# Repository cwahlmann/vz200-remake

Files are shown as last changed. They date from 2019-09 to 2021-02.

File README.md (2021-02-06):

# vz200-remake
Ein Nachbau des VZ200 Color Computers (Vtech / Dick Smith 1983)

**[==>> RESOURCEN & DOWNLOADS <<==](#resourcen-und-downloads)** 

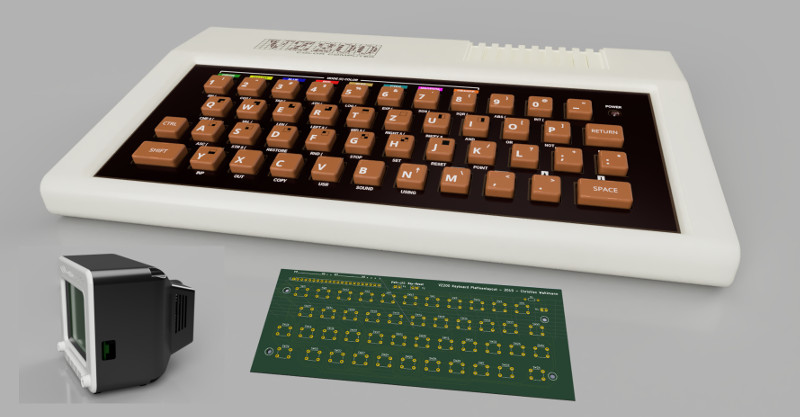
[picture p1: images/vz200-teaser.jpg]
Teaser VZ200 - 70%


**[=> Design und Druck der Bauteile](01_druck.md)**

**[=> Platinendesign und -produktion](02_platinendesign.md)**

**[=> Zusammenbau des VZ200](03_zusammenbau_vz200.md)**

**[=> Zusammenbau des Monitors mit TFT-Display, Raspberry-Pi und Lautsprecher](04_zusammenbau_monitor.md)**

**[=> Installation des Raspberry Pi](05_installation.md)**

**[=> Der VZ200 Emulator](06_emulator.md)**

**[=> VZ200 Companion App](apps/README.md)**

**[=> Nützliche Links](08_links.md)**

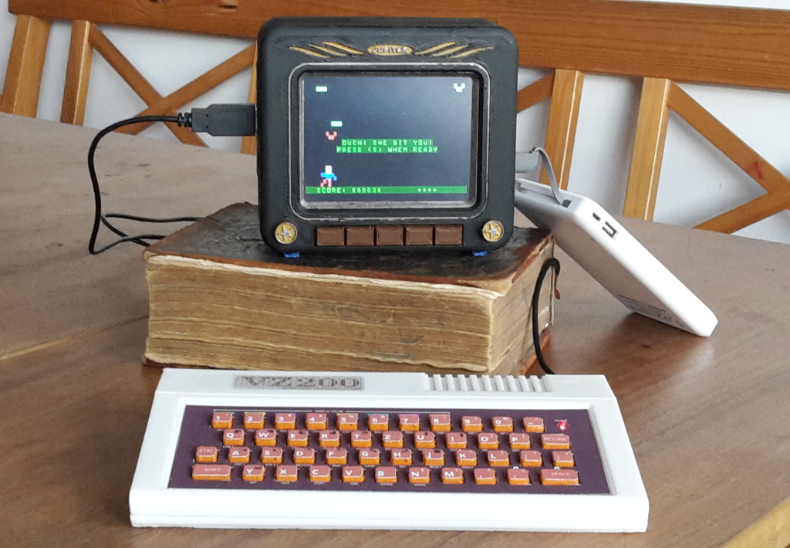
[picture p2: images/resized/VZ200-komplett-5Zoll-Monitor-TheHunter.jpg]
Prototyp VZ200 - 70%


## Resourcen und Downloads

Hardware
* [STL files auf Thingiverse](https://www.thingiverse.com/thing:4415555)
* [3d-Modell VZ200 (.f3d, Fusion 360)](resources/3d-model/vz200.f3d)
* [3d-Modell VZ200 (.fbx, Blender-kompatibel)](resources/3d-model/vz200.fbx)
* [3d-Modell Monitor (.f3d, Fusion 360)](resources/3d-model/Monitor_5-Zoll.f3d) 
* [3d-Modell Monitor (.fbx, Blender-kompatibel)](resources/3d-model/Monitor_5-Zoll.fbx) 
* [Gerber-Dateien für die Tastaturplatine](resources/gerber/vz200-keyboard-layout.zip)
* [Grafiken für die Tastatur](resources/aufkleber/Aufkleber-2x70perc.png)
* [Grafiken für das Logo](resources/aufkleber/logo_7x70perc_A4.png)

Software
* [JemuVZ200 Emulator V2.4 - NEW australian gfx mod, fix issue with vz loader](resources/releases/JemuVZ200-2.4.zip)
* VZ200 Companion App (TODO)

Dokumentation und Beispiele
* [Z80 Befehlssatz](resources/doc/z80.pdf)
* [VZ200 Basic Befehlssatz](resources/doc/VZ200-Basic.pdf)
* ["Hello World" (Assembler) Tutorial](resources/doc/tutorial/hello-world-asm-tutorial.pdf)
* ["Side Scrolling" (Assembler) Tutorial](resources/doc/tutorial/side-scroll-asm-tutorial.pdf)
* [Tutorial Präsentation (LibreOffice)](resources/doc/tutorial/VZ200-tutorial.odp)

Alle Sourcen sind zu finden unter
* [github.com/cwahlmann/vz200](https://github.com/cwahlmann/vz200)

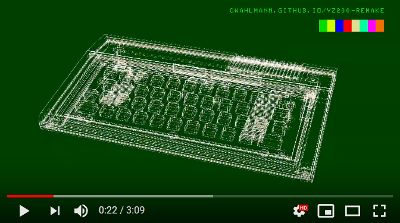
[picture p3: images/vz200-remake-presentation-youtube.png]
VZ200 Presentation Makerfaire (https://www.youtube.com/watch?v=7TxQ1y71ufA)


Basic Programming
Charset
the hunter - bit by a bat

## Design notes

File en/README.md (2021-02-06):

# vz200-remake
A replica of the VZ200 Color Computer (Vtech / Dick Smith 1983)

**[==>> RESOURCES & DOWNLOADS <<==](#resources-and-downloads)** 

Teaser VZ200 - 70%

**[@ Designing and printing the Parts](01_print.md)**

**[@ Cirquit board design and production](02_cirquitboarddesign.md)**

**[@ Assembly of the VZ200](03_assembly_vz200.md)**

**[@ Assembly of the Monitor with TFT Display, Raspberry-Pi and Speaker](04_assembly_monitor.md)**

**[@ Installation of the Raspberry Pi](05_installation.md)**

**[@ The VZ200 Emulator](06_emulator.md)**

**[@ VZ200 Companion App](apps/README.md)**

**[@ Useful Links](08_links.md)**

Prototyp VZ200 - 70%

## Resources and downloads

Hardware
* [STL files on Thingiverse](https://www.thingiverse.com/thing:4415555)
* [3d-Model VZ200 (.f3d, Fusion 360)](../resources/3d-model/vz200.f3d)
* [3d-Model VZ200 (.fbx, Blender-compatible)](../resources/3d-model/vz200.fbx)
* [3d-Model Monitor (.f3d, Fusion 360)](../resources/3d-model/Monitor_5-Zoll.f3d) 
* [3d-Model Monitor (.fbx, Blender-compatible)](../resources/3d-model/Monitor_5-Zoll.fbx) 
* [Gerber-files for the keyboard circuit board](../resources/gerber/vz200-keyboard-layout.zip)
* [graphics for the keyboard](../resources/aufkleber/Aufkleber-2x70perc.png)
* [graphics for the logo](../resources/aufkleber/logo_7x70perc_A4.png)

Software
* [JemuVZ200 Emulator V2.4 - NEW australian gfx mod, fix issue with vz loader](../resources/releases/JemuVZ200-2.4.zip)
* VZ200 Companion App (TODO)

Documentation and examples
* [Z80 instruction set](../resources/doc/z80.pdf)
* [VZ200 Basic instruction set](../resources/doc/VZ200-Basic.pdf)
* ["Hello World" (assembler) tutorial](../resources/doc/tutorial/hello-world-asm-tutorial.pdf)
* ["Side scrolling" (assembler) tutorial](../resources/doc/tutorial/side-scroll-asm-tutorial.pdf)
* [Tutorial presentation (LibreOffice)](../resources/doc/tutorial/VZ200-tutorial.odp)

All Sources are hosted at
* [github.com/cwahlmann/vz200](https://github.com/cwahlmann/vz200)

VZ200 Presentation Makerfaire (https://www.youtube.com/watch?v=7TxQ1y71ufA)

Basic Programming
Charset
the hunter - bit by a bat

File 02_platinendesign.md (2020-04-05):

**[ZURÜCK](README.md)**
# <a name="platinendesign">Platinendesign und -produktion</a>

Eigenes Platinenlayout mit Dip-Schaltern (6mm; Höhe über Platine: 4,5mm; 4 Füße), die über eine Gummi-Tastaturmatte betätigt werden.
Tastaturcontroller: KEYWARRIOR24_8_MODUL_KW24_8_MOD

Das Layout kann, als Zip mit GBR-Dateien, über diverse Anbieter in kleiner Stückzahl (meist >= 3) produziert werden. 

Gute Erfahrungen haben wir mit [Aisler](https://aisler.net) gemacht. 

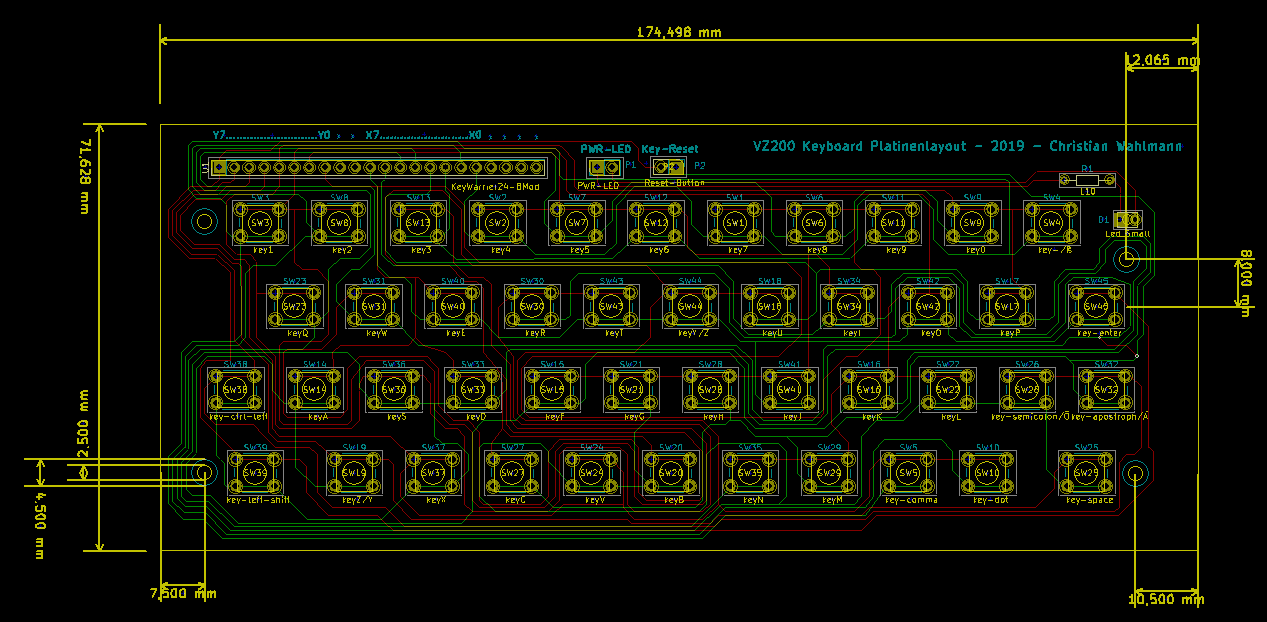
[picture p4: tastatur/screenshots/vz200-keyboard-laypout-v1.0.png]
Platinenlayout Keyboard

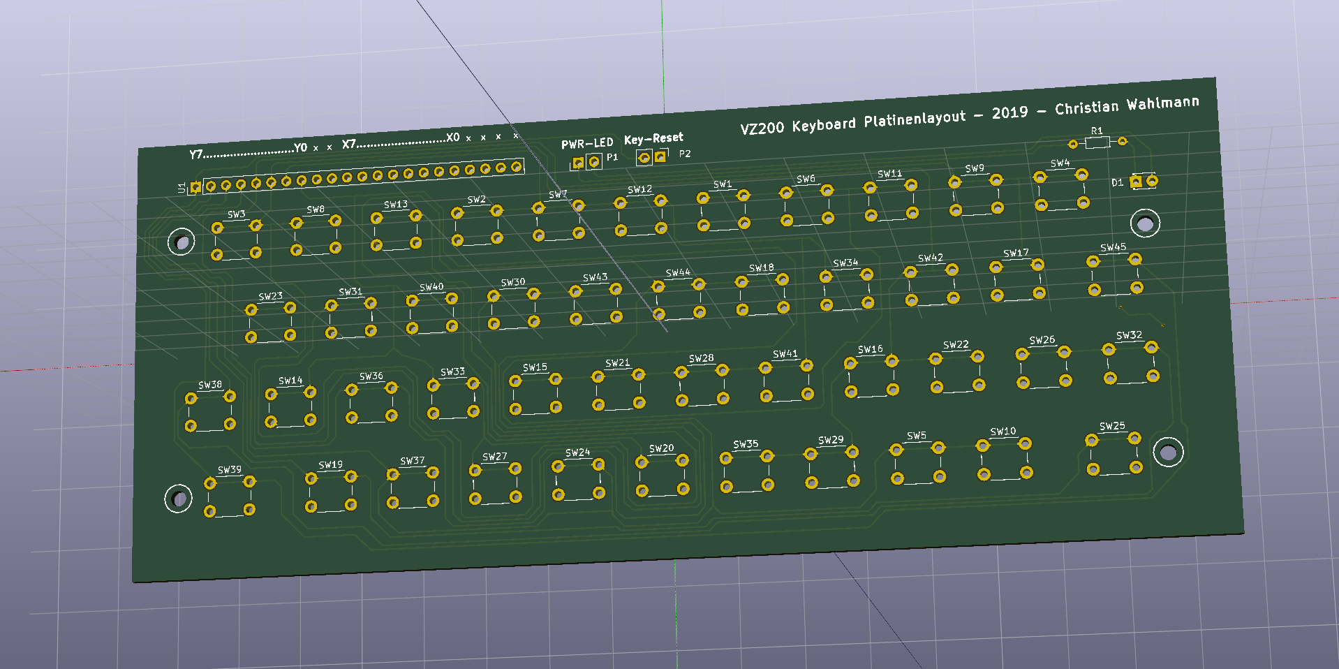
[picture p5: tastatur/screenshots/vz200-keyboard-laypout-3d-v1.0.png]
Platinenlayout Keyboard


**[ZURÜCK](README.md)**

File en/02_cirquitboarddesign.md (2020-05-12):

**[BACK](README.md)**
# <a name="circuitboarddesign">Cirquit board design and production</a>

Custom made cirquit board design with micro switches (6mm; height over board: 4,5mm, four stamps), which are operated through a TPU keyboard mat. Keyboard controller: KEYWARRIOR24_8_MODUL_KW24_8_MOD

This circuit board design can be produced by various workshops in small numbers, mostly require >= 3. Those workshops usually accept a zip file with GBR files.

Our boards were produced by [Aisler](https://aisler.net). 

Circuit design Keyboard
Circuit design Keyboard

**[BACK](README.md)**

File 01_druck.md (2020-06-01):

**[ZURÜCK](README.md)**
# <a name="druck">Design und Druck der Bauteile</a>
## 3d-Modell
Das Modell wurde mit Autodesk Fusion 360 erstellt. 

**Bitte beachten**: Das Modell des Computergehäuses und die darin verbaute Elektronik sind dafür 70% der Originalgröße ausgelegt. Die STL-Dateien geben das bereits wieder; in den Fusion-Dateien (.3mf) hat das Gehäuse noch die Originalgröße. Wer das Modell in Originalgröße nachbauen möchte, muss die Pfosten für den Tastaturcontroller anpassen und die Tastaturplatine entsprechend skalieren, bevor sie geätzt wird. Außerdem muss gegebenenfalls die Position der Resetschalter-Halterung angepasst werden.

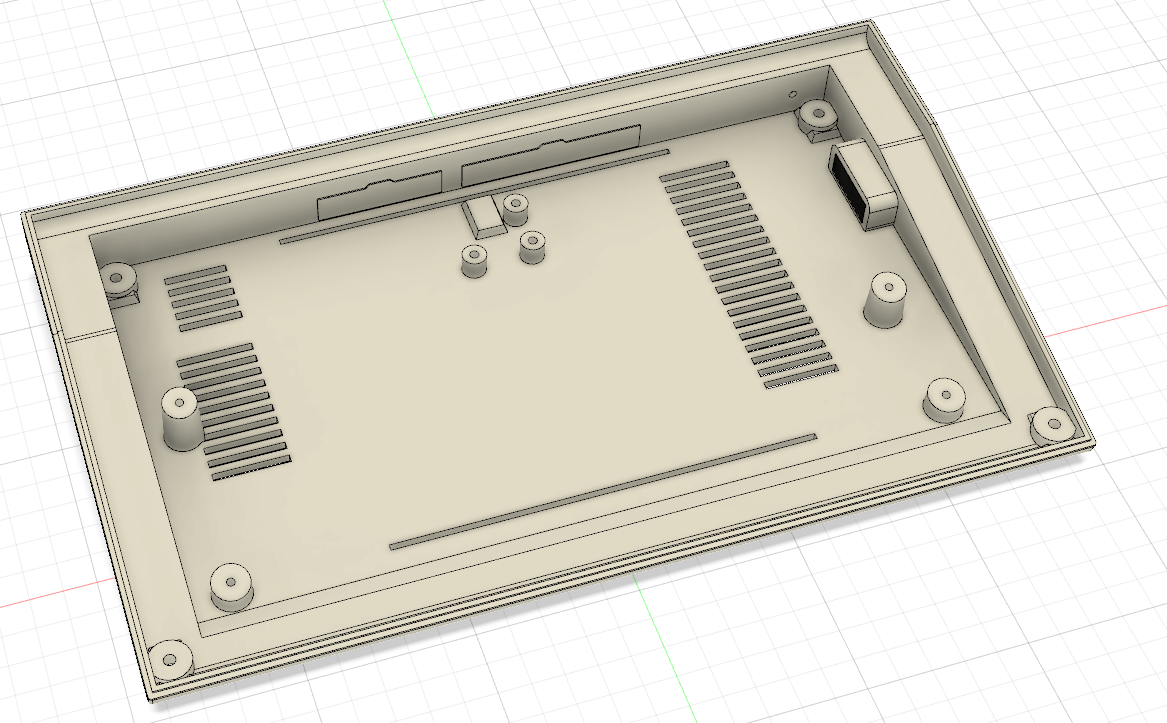
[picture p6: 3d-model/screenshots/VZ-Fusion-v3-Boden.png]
3d-Layout Boden

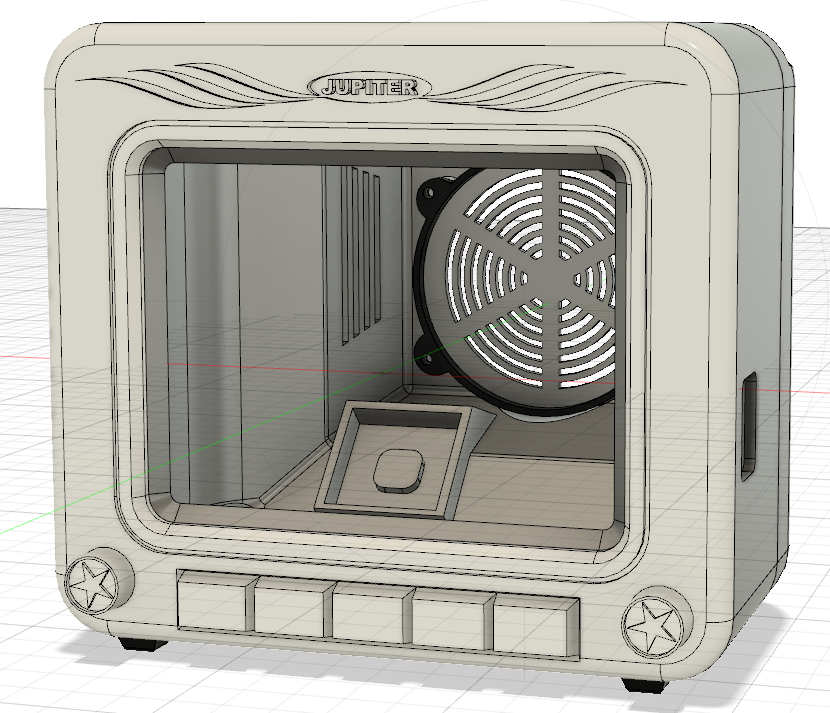
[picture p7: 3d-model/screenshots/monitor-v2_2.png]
3d-Layout Monitor


## Drucke

Druckdateien
* [STL files auf Thingiverse](https://www.thingiverse.com/thing:4415555)
* [3d-Modell VZ200](resources/3d-model/vz200.f3d)
* [3d-Modell Monitor](resources/3d-model/Monitor_5-Zoll.f3d) 

Die aus Fusion 360 exportierten STL-Dateien werden mit Ultimaker Cura 4.x druckfertig gemacht -> Das Projekt enthält gcode-Dateien für Creality Ender 3.

Gedruckt wird mit PLA (Gehäuse, Tastaturschablone, Resetschalter) und TPU-Filament (Tastaturmatte). 

Für den VZ 200 nehmen wir Weiß (Gehäuse), schokoladenbraun (Tastaturabdeckung) und eine beliebige TPU-Farbe für die Tastaturmatte (gummiartig).

**[ZURÜCK](README.md)**

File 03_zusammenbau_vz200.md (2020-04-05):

**[ZURÜCK](README.md)**
# <a name="zusammenbau">Zusammenbau des VZ200</a>

Das Chassis beherbergt eine funktionierende Tastatur mit Power-LED und Reset-Taster.

Bei einer Größe von 70 Prozent gegenüber dem Original-Rechner passt der Raspberry Pi nicht mit ins Gehäuse. Dieser wird deshalb in
den Monitor integriert. Der VZ200 wird als USB-Tastatur an den Raspberry angeschlossen. 

(Ein Raspberry-Zero würde in das Gehäuse passen, es muss jedoch getestet werden, ob dieser für den Emulator genügend Rechenpower liefert.)

## benötigte Bauteile

| Bauteil | Beschreibung |
| --- | --- |
| Gedruckte Teile | Boden, Abdeckung hinten, Tastatur (Rahmen, Schablone, Tastenmatte), Resetschalter + Klammer |
| Gedrucktes Logo | klare, selbstklebende, transparente A4 Polyesterfolie für Tintenstrahldrucker (z.B. von Photo Paper Direct PPD-39-20) |
| Gedruckte Tasten auf Vinylfolie | weiße, matte, selbstklebende A4 Vinylfolie für Tintenstrahldrucker (z.B. von Photo Paper Direct PPD-38-10) |
| Gedruckte Tastaturschablone auf Vinylfolie | weiße, matte, selbstklebende A4 Vinylfolie für Tintenstrahldrucker (z.B. von Photo Paper Direct PPD-38-10) |
| Modellfarbe für Tasten | EMAIL COLOR von Revell, Matt 35 (Hautfarben) und Matt 85 (Braun) |
| Tastaturplatine | mit Hilfe des Platinendesigns kann die Platine über diverse Anbieter gefertigt werden |
| Tastaturcontroller | ein USB-Keyboard-Controller mit vordefinierter Belegung: KEYWARRIOR24_8_MODUL_KW24_8_MOD |
| USB-Kabel | USB-Kabel mit Stecker und Litzen zum Einlöten |
| 45 Drucktaster | Bestückung der Tastaturplatine, 6x6 mm |
| 1 rote LED | die Power-LED, 3mm |
| 1 Widerstand | 150 Ohm (braun / grün / braun) |
| ein Stück Lochplatine | für den Drucktaster des Resetschalters, Lochabstand 2.54 mm |
| 1 Drucktaster | für den Resetschalter, 6x6 mm |
| 2 x Rot-Weiße Litze ca. 10 cm | für den Resetschalter und die Power-LED |
| 2 x 8-adriges Flachbandkabel ca. 10 cm | z.B. aus alten IDE-Flachbandkabeln, für die Verbindung Tastaturcontroler -> Tastaturplatine |
| ein Stück Isolierband | Abschirmung von Reset-Schalter und Tastaturplatine | 
| 7 kurze Schrauben M2 5mm | Befestigung von Tastaturplatine und -Controller |
| 2 kurze Schrauben M2 8mm | Befestigung der Reset-Schalter-Platine |
| 2 kurze M2 5mm und 2 lange M2 20mm Schrauben | Zusammenbau des Gehäuses |

## hintere Gehäuseabdeckung mit Logo versehen
Aufkleber Logo

Das gedruckt Logo muss wie abgebildet auf der hinteren Gehäuseabdeckung angebracht werden.

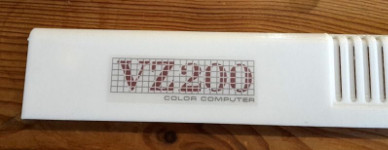
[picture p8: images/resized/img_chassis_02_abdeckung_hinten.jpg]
Abdeckung hinten


## Tastatur zusammenbauen
Benötigt werden die gedruckte Tastaturmatte, Modellfarbe und die gedruckten Tastenaufkleber.

Die Tasten der Matte müssen zunächst mit der Farbe (Matt 35, Hautfarben) mit einem Pinsel grundiert und dann
mit (Matt 85, Braun) gestrichen werden. Es sollten nur die Tasten selbst bemalt werden, damit die Matte gut zwischen Platine und Tastaturschablone passt und die Tasten leichtgängig bleiben. Ein Färben mit Sprühlack ist nicht zu empfehlen.

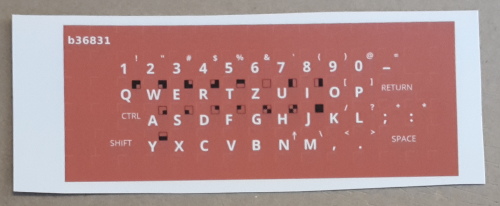
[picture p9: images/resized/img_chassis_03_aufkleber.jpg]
Tastaturmatte und Aufkleber Aufkleber

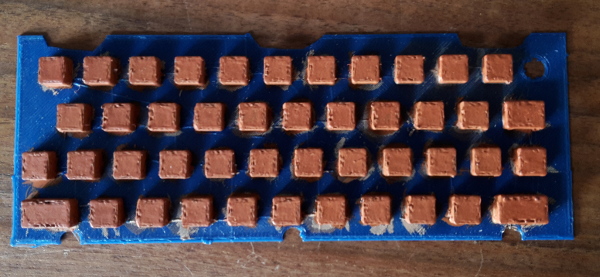
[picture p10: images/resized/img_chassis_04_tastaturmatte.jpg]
Tastaturmatte und Aufkleber Tastaturmatte


Die Aufkleber werden nun geschnitten.

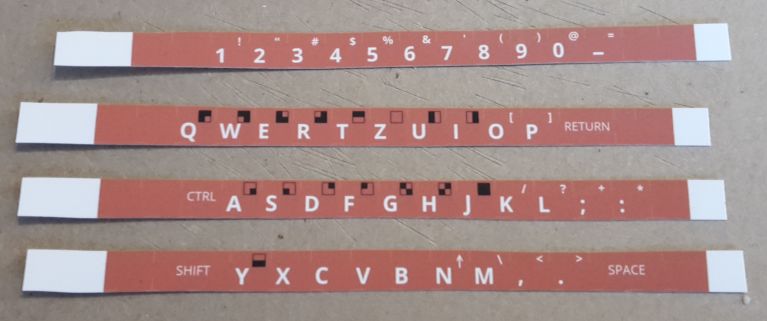
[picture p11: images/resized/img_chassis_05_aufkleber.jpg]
Tastaturaufkleber schneiden

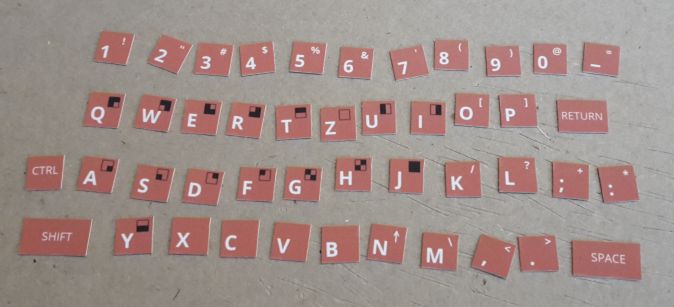
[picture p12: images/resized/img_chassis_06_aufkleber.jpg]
Tastaturaufkleber schneiden 2


Wichtig ist: damit die Tasten einen runden Eindruck machen, sollten die Ecken der Aufkleber diagonal angeschnitten werden.

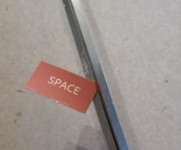
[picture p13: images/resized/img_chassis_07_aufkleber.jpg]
Tastaturaufkleber schneiden 3

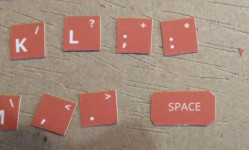
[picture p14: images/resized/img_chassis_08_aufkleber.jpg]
Tastaturaufkleber schneiden 4

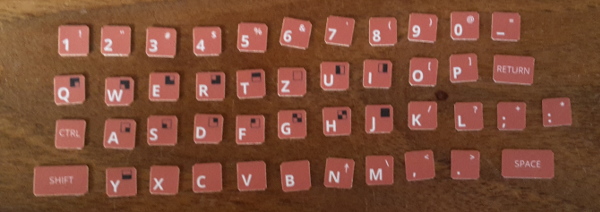
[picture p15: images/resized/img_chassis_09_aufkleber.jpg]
Tastaturaufkleber schneiden 5


Die geschnittenen Aufkleber werden auf die Tastaturmatte geklebt.

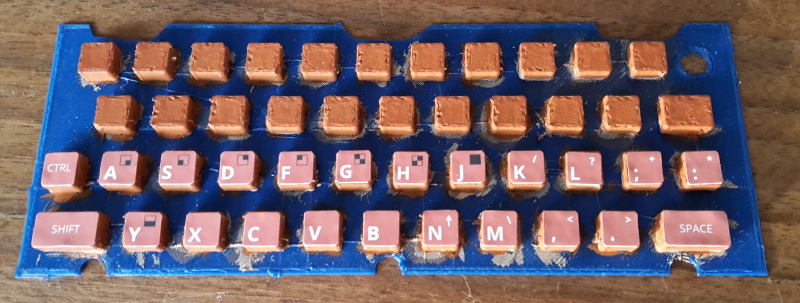
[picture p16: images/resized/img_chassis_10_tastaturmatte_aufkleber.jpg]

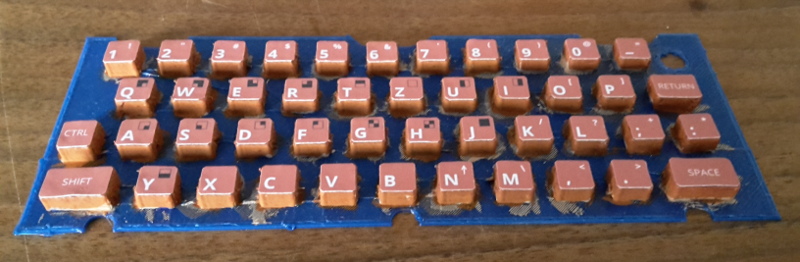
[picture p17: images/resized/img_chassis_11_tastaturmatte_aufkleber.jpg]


Nun wird die Tastaturschablone vorbereitet. Dazu wird die gedruckte Schablone und der gedruckte Aufkleber benötigt.

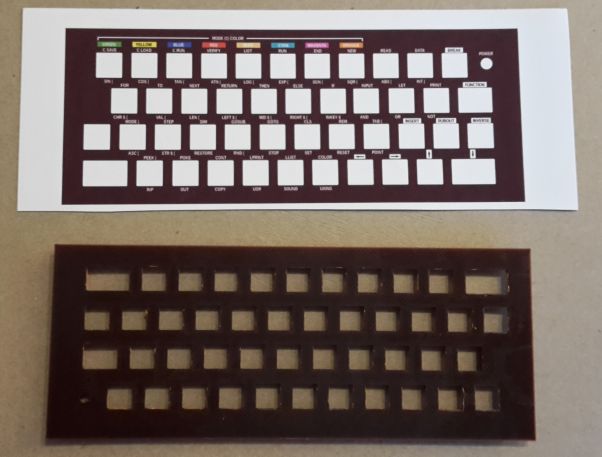
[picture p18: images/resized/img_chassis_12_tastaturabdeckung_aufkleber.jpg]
Tastaturschablone Aufkleber


Die Aussparungen für die Tasten und die Power-LED werden mit dem Cutter herausgetrennt.

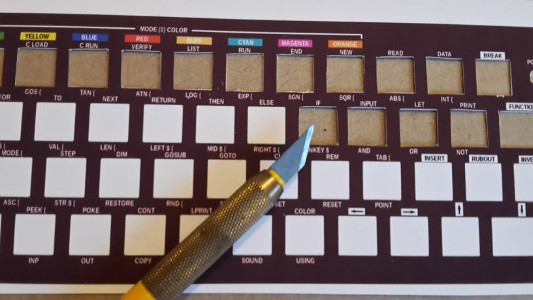
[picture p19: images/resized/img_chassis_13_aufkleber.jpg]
Tastaturschablone Aufkleber schneiden

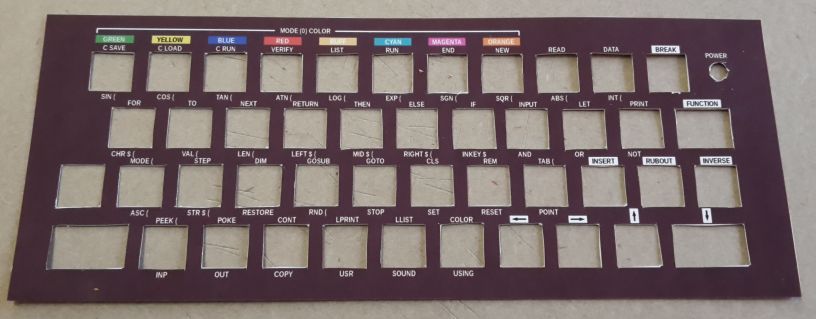
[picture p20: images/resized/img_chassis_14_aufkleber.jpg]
Tastaturschablone Aufkleber schneiden 2


Dann wird der Aufkleber auf die Schablone geklebt. Wichtig ist, dass die Aussparungen mittig auf die der Schablone geklebt werden. Dabei bleibt ein kleiner Rand, damit sich die Tasten nicht am Aufkleber verhaken.

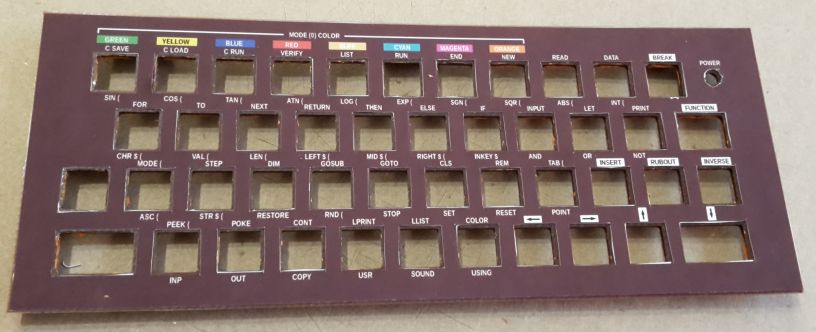
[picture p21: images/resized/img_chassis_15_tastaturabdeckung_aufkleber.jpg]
Tastaturschablone bekleben


Nun wird die Tastenmatte von hinten in die Schablone gesteckt, und die Schablone in den Tastaturrahmen eingehakt.

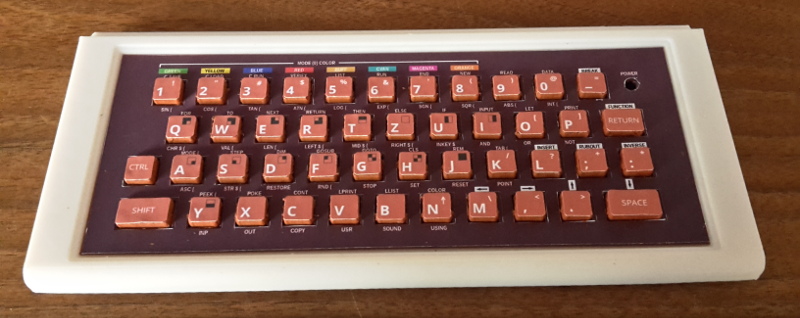
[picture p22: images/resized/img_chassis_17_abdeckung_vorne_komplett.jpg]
Tastaturschablone an Rahmen anbringen

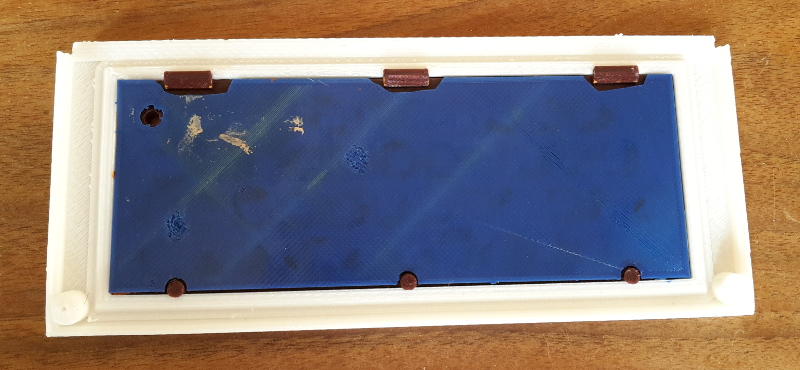
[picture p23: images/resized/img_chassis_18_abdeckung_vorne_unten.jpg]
Tastaturschablone im Rahmen unten


## Verlöten und Einbau der Elektronik

Im Bild eine Übersicht der benötigten Einzelteile:

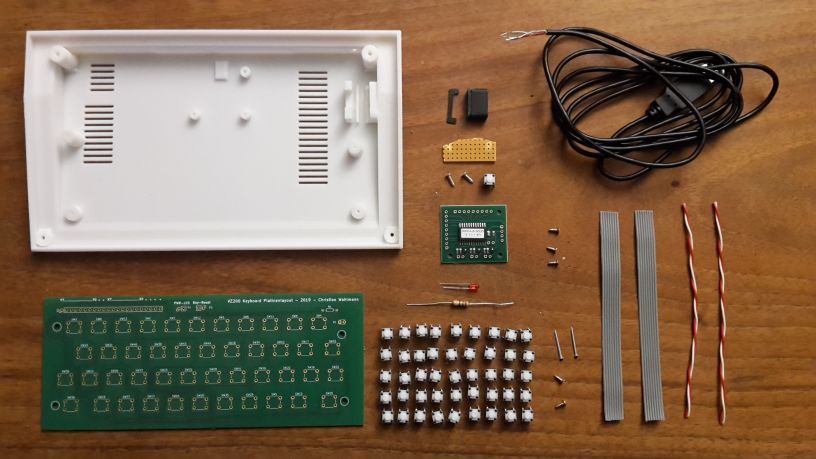
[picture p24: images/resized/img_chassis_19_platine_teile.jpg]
Bauteileübersicht Platine


Der Resettaster wird auf die zugeschnittene Lochplatine gesteckt.

Resettaster
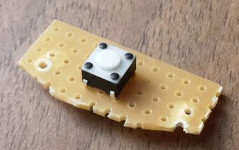
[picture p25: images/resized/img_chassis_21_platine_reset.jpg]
Resettaster 2


 Mit der Rot-weißen Litze wird der Taster mit der Tastaturplatine verbunden.

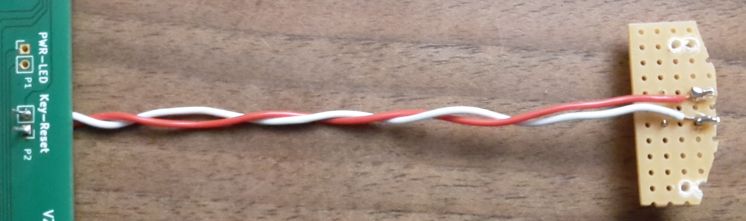
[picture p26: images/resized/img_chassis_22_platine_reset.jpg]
Resettaster 3


Dann werden noch zwei der kurzen Schrauben in die Platine geschraubt, zur späteren Befestigung am Boden des Gehäuses.

Resettaster 4

Das USB-Kabel wird wie abgebildet mit dem Tastaturcontroller verbunden.
**Achtung:** Das Kabel muss vor dem Löten durch das Loch des Gehäuseunterteils geführt und einfach verknotet werden!

| USB-Kabel Litzenfarbe | Controller Anschluss | 
| --- | --- |
| Rot | +5V |
| Weiß | D- |
| Grün | D+ |
| Schwarz | GND |

An +5V und GND wird zusätzlich die zweite Rot-Weiße Litze für die Power-LED angelötet:

| Power-LED Litzenfarbe | Controller Anschluss | 
| --- | --- |
| Rot | +5V |
| Weiß | GND |

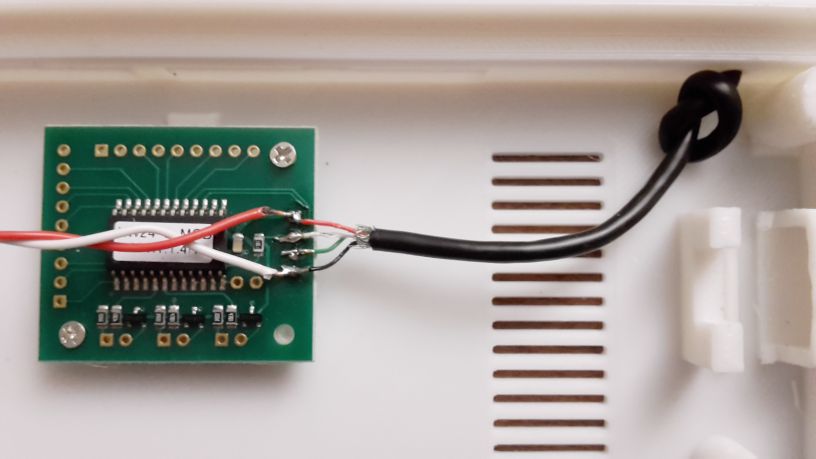
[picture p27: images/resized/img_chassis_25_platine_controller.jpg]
Tastaturcontroller 2


Nun werden die grauen Flachbandkabel an den Controller gelötet, an die Anschlüsse X0-X7 und Y0-Y7:

Tastaturcontroller 3
Tastaturcontroller 4

Jetzt wird die Tastaturplatine mit Tastern, der Power-LED und dem Vorwiderstand für die LED bestückt:

Platine Taster

Der Plus-Pol der LED (langes Bein) muss in den quadratischen Lötkontakt der Platine gelötet.

Platine Power-LED

Die Ausrichtung der Taster ergibt sich aus den Abständen der Lötkontakte auf der Platine.

Platine Taster 2

Nun wird die Rot-weiße Litze, welche an +5V / GND des Tastaturcontrollers angelötet ist, an die Tastaturplatine angelötet. Der weißumrandete Lötkontakt ist Minus (weiße Litze), der quadratische Kontakt ist Plus (rote Litze).
Danach werden die beiden Flachbandkabel an die Tastaturplatine gelötet. Hier ist sehr auf die Ausrichtung zu achten, die Lötkontakte der Tastaturplatine sind mit x0-x7 und y0-y7 beschriftet.

Platine Controller
Platine Controller 2

Nun wird der Reset-Taster ins Gehäuse eingebaut. Zunächst wird der gedruckte Reset-Schalter in das Gehäuse geschoben und mit der Klammer gesichert.

Platine Resettaster
Platine Resettaster 2

Dann wird die Platine mit dem Drucktaster aufgesetzt.

Platine Resettaster 3

Nun wird der Tastaturcontroller mit drei kurzen Schrauben in das Gehäuse geschraubt.

Platine Einbau

Auf den Reset-Taster wird etwas Isolierband geklebt, damit die Schraube unter der Tastaturplatine keinen Kurzschluss verursachen kann.

Platine Einbau 2

Die Platine wird mit vier kurzen Schrauben im Gehäuse befestigt.

Platine Einbau 3

Zuletzt werden der Tastaturrahmen und das hintere Gehäuseteil aufgesetzt und auf der Rückseite mit zwei langen und zwei kurzen Schrauben befestigt.

Zusammenbau Chassis
Zusammenbau Chassis 2
Zusammenbau Chassis 3

Damit ist der VZ200 fertig. Der Emulator "JEmu" kann übrigens sowohl auf einem Raspberry PI als auch auf einem PC betrieben werden. Der VZ200 fungiert dabei als USB-Tastatur.

Hinweis: Falls die Tastatur prellt (mehrere Zeichen pro Tastendruck erzeugt) oder verschiedene Buchstaben auf einmal erscheinen, dann gibt es vermutlich einen Kurzschluss zwischen zwei Microschaltern. Das kann schnell passieren, falls nicht alle der sehr feinen Litzen der Kabel sauber verlötet werden und ggf. zur Seite wegstehen. 

Um das zu beheben, empfehlen wir, die Platine von beiden Seiten um die betreffenden Tasten herum unter einer starken Lampe genau zu betrachten, eventuell unter der Zuhilfenahme einer Lupe. Selbst feinste Drähtchen reflektieren das Licht aus einem bestimmten Blickwinkel. Diese dann mit einem Cutter abheben und abschneiden, um den Kurzschluss zu beheben. 

Weitere Fehlerquelle: Kalte Lötstellen (das gilt für den kompletten Zusammenbau). Diese erkennt man daran, dass der Lötzinn nicht glänzt, sondern leicht matt und milchig erscheint. Diese Stellen bitte noch einmal nachlöten. 

**[ZURÜCK](README.md)**

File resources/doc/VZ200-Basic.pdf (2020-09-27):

VZ200 Basic Cheat Sheet

VZ200-Remake | github.com/cwahlmann/vz200-remake | Seite 1 von 2
REM <kommentar> | ein Kommentar | REM *** START ***
PRINT [<var1>;<...>;<varN>] | Ausgabe mit Zeilenumbruch | PRINT "HALLO";$N
PRINT <...>; | Ausgabe ohne Zeilenumbruch | PRINT "SAG MAL WAS";
PRINT @<n>,<...> | | PRINT @128,"ZEILE 5"
PRINT TAB(<n>);<...> | | PRINT TAB(3);“3“;TAB(20);“20“
| Formatierte Ausgabe
INPUT <var1>[,<...>,<varN>] | Eingabe von einer oder mehrerer Werte | INPUT A$, X, Y
NEW | Programmspeicher löschen | NEW
RUN [<n>] | Programm (ab Zeile n) starten | RUN 30
[LET] <var>=<wert> | Wert einer Variablen zuweisen
LIST [[n]-[m]] | Programm (Zeilen m bis n> auflisten | LIST -100
GOTO <n> | zu Zeile n springen | GOTO 20100
STOP | das Programm unterbrechen | STOP
CONT | das Programm fortführen | CONT
END | | END
CLEAR [<n>] | | CLEAR 5000
ABS(<n>) | liefert den positiven Wert einer Zahl | X = ABS(-12.33):REM 12.33
SGN(<n>) | | X = SGN(-12.33):REM -1
SQR(<n>) | liefert die Wurzel einer Zahl | E = SQR(25):REM 5
LOG(<n>) | | L = LOG(4.44):REM 1.49065
EXP(<n>) | liefert den Wert e^n | E = EXP(1):REM 2.71828
INT(<n>) | liefert den ganzahligen Anteil einer Zahl | I = INT(1.9334):REM 1

RND(<n>)

SIN(<n>) | liefert den Sinuswert einer Zahl
COS(<n>) | liefert den Cosinuswert einer Zahl | X = COS(W/180*3.1415):REM .866033
TAN(<n>) | liefert den Tangenswert einer Zahl | T = TAN(W/180*3.1415):REM .57733
ATN(<n>) | liefert den Arcus-Tangenswert einer Zahl | W = ATN(X/Y)/3.1415*180:REM 30
LEN(<string>) | liefert die Länge eines Strings | PRINT LEN("HALLO")
STR$(<n>) | wandelt eine Zahl in einen String um | PRINT STR$(1277):REM "1277"
VAL(<string>) | wandelt einen String in eine Zahl um | PRINT VAL("1277"):REM 1277
LEFT$(<string>, <n>) | liefert die ersten n Zeichen eines Strings | L$ = LEFT$("NINA",2): REM NI
RIGHT$(<string>, <n>) | liefert die n letzten Zeichen eines Strings | R$ = RIGHT$("NINA",2):REM NA
MID$(<string>, <m>, <n>) | liefert n Zeichen ab Position m eines Strings M$ = MID$("NINA",2,2):REM IN
ASC(<string>) | | PRINT ASC("A"):REM 65
CHR$(<n>) | wandelt einen Ascii-Wert in einen String um | PRINT CHR$(65):REM A
INKEY$ | | 10 IF INKEY$="" THEN 10
= < > <= >= <> | Vergleichsoperatoren
<bool> AND|OR|NOT <bool> | logische Und/Oder/Nicht-Verknüpfung | 20 IF A=2 AND B=3 THEN 40

setzt den Cursor an die angegebenen Position, n=x+32*y
setzt den Cursor weiter zu angegebenen Position innerhalb der Doppelzeile PRINT USING <format>;
<var1>,<…>,<varN>

PRINT USING "##.## / ##.##"; 1.23, 0.75

LET X=7
I%=-9
B$="PETER"

das Programm beenden (kein CONT mehr möglich)
dem Programm n Bytes Speicher reservieren (Default: 50 bytes)

liefert das Vorzeichen einer Zahl (-1, 0 oder 1)

liefert den natürlichen Logarithmus einer Zahl

liefert eine Zufallszahl zwischen 1 und n, oder eine rationale Zahl zwischen 0 und 1 für n=0

IF RND(2)=1 THEN PRINT "TOP" ELSE PRINT "FLOPP"

W=30:Y = SIN(W/180*3.1415):REM .499987

liefert den Ascii-Wert des ersten Zeichens eines Strings

liest ein Zeichen von der Tastatur, ohne zu warten
IF <bedingung>
THEN <befehl-true>
[ELSE <befehl-false>]

Bedingte Ausführung, je nach Ergebnis der Bedingung

IF A>=2 THEN PRINT "MEHRERE ERBSEN" ELSE PRINT "EINE ERBSE" IF X=0 THEN PRINT "NULL"

VZ200 Basic Cheat Sheet

VZ200-Remake | github.com/cwahlmann/vz200-remake | Seite 2 von 2
<n> AND|OR|NOT <m> | bitweise Und/Oder/Nicht-Verknüpfung | E = 3 OR 6:REM 7
| Zählt var von n bis m (mit Schrittweite s) | FOR I=10 TO 1 STEP -1:PRINT I:NEXT
NEXT [<var>] | | NEXT I
GOSUB <n> | Aufruf des Unterprogramms ab Zeile n | GOSUB 12345
RETURN | Unterprogramm beenden | RETURN
DIM <var>(<m>[,<n>[,<o>]]) | | DIM R$(2,5)
DATA <n1>[,<n2>,<...>] | Daten bereitstellen | DATA 1,2,"PILLE",3,4,"PALLE"
READ <var1>[,<var2>,<...>] | Daten in Variablen einlesen | READ A,B,M$
RESTORE | | RESTORE
PEEK(<adresse>) | liefert Wert einer Speicherstelle | B = PEEK(28672)
POKE <adresse>,<wert> | schreibt einen Wert in den Speicher
CLOAD ["<filename>") | lädt ein Programm von Cassette | CLOAD "SUPERSPIEL"
CRUN ["<filename>") | führt ein Programm von Cassette aus | CRUN "MEGASPOILER"
CSAVE ["<filename>") | Schreibt ein Programm auf Cassette | CSAVE "MEINS"
VERIFY ["<filename>") | | VERIFY "MEINS"
| Schreibt Werte auf Cassette | PRINT# "DATEN",1,2,"PILLE"
| liest Werte von Cassette | INPUT# "DATEN",A,B,M$
MODE(<n>) | | MODE(1)
SET(<x>,<y>) | setzt einen Grafikpunkt | SET(10,10)
RESET(<x>,<y>) | löscht einen Grafikpunkt | RESET(9,10)
POINT(<x>,<y>) | liefert die Farbe eines Grafikpunkts | 60 IF POINT(9,10)=0 THEN 100
SOUND <note>,<länge> | | SOUND 13,7:SOUND 0,4:SOUND 15,7
INP(<n>) | liest einen Wert von Port n | B=INP(123)
OUT <n>,<wert> | schreibt einen Wert in Port n | OUT 123,4

USR(<n>)

LLIST, LPRINT | wie LIST und PRINT, aber auf Druckerport
COPY | | COPY
Variablennamen | [A-Z]([A-Z0-9])?(%|$)? | A1$="MOIN": XY=9.333
String | eine Zeichenkette | S$="GUTEN TAG"
Float | | PI=3.1415927:m=1E9
Integer | eine Ganzzahl zwischen -32768 und 32767 | Z9%=16384

Textmodus

Grafikmodus | 128x64 Pixel, 4 Farben, 2 Paletten

FOR <var>=<n> TO <m>
[STEP <s>]
springe zum nächsten Schleifendurchlauf (der Indexvariable var)

Arrayvariablen deklarieren (1, 2 oder 3-dimensional)

Beim Lesen von Daten wieder von vorne beginnen

POKE 28672,1:REM EIN "A" LINKS OBEN AM SCREEN

Vergleicht auf Cassette gespeichertes Programm mit dem aktuellen Programm im Speicher
PRINT# "<filename>",
<wert1> [,<wert2><...>]
INPUT# "<filename>",
<var1> [,<var2><...>]
setzt den Grafikmodus
(0 = Text, 1 = Hires)

COLOR [<vordergrund>]
[,<palette>]

Setzt Vordergrundfarbe und / oder die Hintergrundfarbe

COLOR 4: REM VORDERGRUND BLAU COLOR ,0: REM HINTERGRUND GRÜN COLOR 1,1: REM GELB / CYAN Spielt einen Ton ab
note: 0 = Pause; 1 = A2; 31 = D#5 länge: 1-4 = n/8; 5= ¾; 7 = 1 ½; 6-9 = 1-3

Ruft eine benutzerdefinierte Maschinenroutine auf.
Startadresse: 788e (30862) Wert n:7921 (31009)

POKE 30862,LO:REM LOWBYTE DES PRG POKE 30863,HI:REM HIGHBYTE DES PRG E=USR(1234)

LLIST
LPRINT "HALLO DRUCKER"
macht einen Screenshot auf dem Druckerport

eine Fließkommezahl zwischen -1.701411E+/-38 und -1.701411E+/-38

32x16 Zeichen,
8 Farben, 2 Hintergrundfarben

grün, gelb, blau, rot, weiss, türkis, magenta, orange / grün, orange grün, gelb, blau, rot / weiss, türkis, magenta, orange

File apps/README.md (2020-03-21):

# VZ200 Companion App

This App supports the retro enthusiast while dealing with the VZ200 - Emulator. It allows for doing file transfers and operations on the emulated device as well as organizing files made available to the emulation. 



## Installation / prerequisites

### Install NPM

Download and install NodeJS from the official site.

https://nodejs.org/en/download/

### Install Ionic

> npm install -g ionic

### Install git

https://git-scm.com/downloads

## Build and run the App

Checkout the App from this repo into a directory of your choice:

> git clone https://github.com/cwahlmann/vz200/new/master/apps/VZ200-App

Install dependencies

> npm i

Run the App

> ionic serve

The App should be available at http://localhost:4200

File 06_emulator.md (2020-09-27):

**[ZURÜCK](README.md)**
# <a name="emulator">Der VZ200 Emulator</a>

Der genutzte Emulator ist eine angepasste Version des Java-Emulators 'jemu': http://jemu.winape.net/

## Port Konfiguration

application.properties (Default 8080):

```
server.port = 10101
```

Reset-Taste: [ESC]

## Erweiterung Netzwerk-Info

```basic
OUT 250,0:FOR I=1 to 4:PRINT INP(250);:NEXT
192 168 1 100
READY
```

PORT | IN / OUT | Beschreibung
-----|----------|-------------
250  | IN       | READ part of IP-Adress at [index] and increment [index]
250  | OUT      | SET [index] to [n] (0-3)

## Erweiterung Audio Device

```basic
OUT 251,0:REM SOUND OFF
READY
OUT 251,INP(251)+50:REM DO IT LOUDER
READY
```

PORT | IN / OUT | Beschreibung
-----|----------|-------------
251  | IN       | READ sound volume
251  | OUT      | SET sound volume to [n]

## Erweiterung laden / speichern von .vz:

```basic
OUT 252,1
READY
```

PORT | IN / OUT | Beschreibung
-----|----------|-------------
252  | OUT      | LOAD .vz program no. [n]
253  | OUT      | SAVE .vz program no. [n]

Alle Programme n <= 100 sind readonly.

(werden in [home]/vz200/vz abgelegt)

## Erweiterung Tape-Controle

```basic
PRINT INP(254)
10
READY
```

PORT | IN / OUT | Beschreibung
-----|----------|-------------
254  | OUT      | 0: STOP, 1: PLAY, 16: RECORD
255  | OUT      | REWIND to position [n]
254, 255  | IN  | get LSB / MSB of tape position

(werden in [home]/vz200/tape abgelegt)

## REST-Interface

Informationen zu den einzelnen Methoden können online abgerufen werden:

* Swagger-UI: [host:port]/api/swagger
* Open-API-Doc: [host:port]/v3/api-docs

## Australian Graphics Mod

PORT | IN / OUT | Beschreibung                        | Format
-----|----------|-------------------------------------|--------------------------------------------------
32   | OUT      | Grafikmodus und Gfx-RAM-Page setzen | ---MMMPP (MMM = Modus 0-7, PP = Gfx-RAM-Page 0-3)

| MODUS | Beschreibung
|---|---
| 0 | 64x64, 4 colors
| 1 | 128x64, monochrome
| 2 | 128x64, 4 colors (default)
| 3 | 128x96, monochrome
| 4 | 128x96, 4 colors
| 5 | 128x192, monochrome
| 6 | 128x192, 4 colors
| 7 | 256x192, monochrome

Der Mod kann über die Konfigurationsdatei ~/.jemu deaktiviert / aktiviert (default) werden.

**[ZURÜCK](README.md)**

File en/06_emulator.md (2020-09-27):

**[BACK](README.md)**
# <a name="emulator">The VZ200 Emulator</a>

This Emulator is an adapted Variant of the Java-Emulator 'jemu': http://jemu.winape.net/

## Port Configuration

application.properties (Default 8080):

```
server.port = 10101
```

Reset Key: [ESC]

## Expansion to get network info

```basic
OUT 250,0:FOR I=1 to 4:PRINT INP(250);:NEXT
192 168 1 100
READY
```

PORT | IN / OUT | Description
-----|----------|-------------
250  | IN       | READ part of IP-Adress at [index] and increment [index]
250  | OUT      | SET [index] to [n] (0-3)

## Expansion for audio

```basic
OUT 251,0:REM SOUND OFF
READY
OUT 251,INP(251)+50:REM DO IT LOUDER
READY
```

PORT | IN / OUT | Description
-----|----------|-------------
251  | IN       | READ sound volume
251  | OUT      | SET sound volume to [n]

## Expansion to load and save .vz files:

```basic
OUT 252,1
READY
```

PORT | IN / OUT | Description
-----|----------|-------------
252  | OUT      | LOAD .vz program no. [n]
253  | OUT      | SAVE .vz program no. [n]

All programs with n <= 100 are readonly and have be stored in [home]/vz200/vz.

## Expansion Tape Control

```basic
PRINT INP(254)
10
READY
```

PORT | IN / OUT | Description
-----|----------|-------------
254  | OUT      | 0: STOP, 1: PLAY, 16: RECORD
255  | OUT      | REWIND to position [n]
254, 255  | IN  | get LSB / MSB of tape position

(Stored in [home]/vz200/tape)

## REST Interface

Information about the provided methods is available online at:

* Swagger-UI: [host:port]/api/swagger
* Open-API-Doc: [host:port]/v3/api-docs

## Australian Graphics Mod

PORT | IN / OUT | Description                       | FORMAT    
-----|----------|-----------------------------------|--------------------------------------------------
32   | OUT      | set graphic-mode und Gfx-RAM-Page | ---MMMPP (MMM = mode 0-7, PP = gfx-RAM-page 0-3)

| MODE  | Description
|---|---
| 0 | 64x64, 4 colors
| 1 | 128x64, monochrome
| 2 | 128x64, 4 colors (default)
| 3 | 128x96, monochrome
| 4 | 128x96, 4 colors
| 5 | 128x192, monochrome
| 6 | 128x192, 4 colors
| 7 | 256x192, monochrome

Der Mod kann über die Konfigurationsdatei ~/.jemu deaktiviert / aktiviert (default) werden.

**[BACK](README.md)**

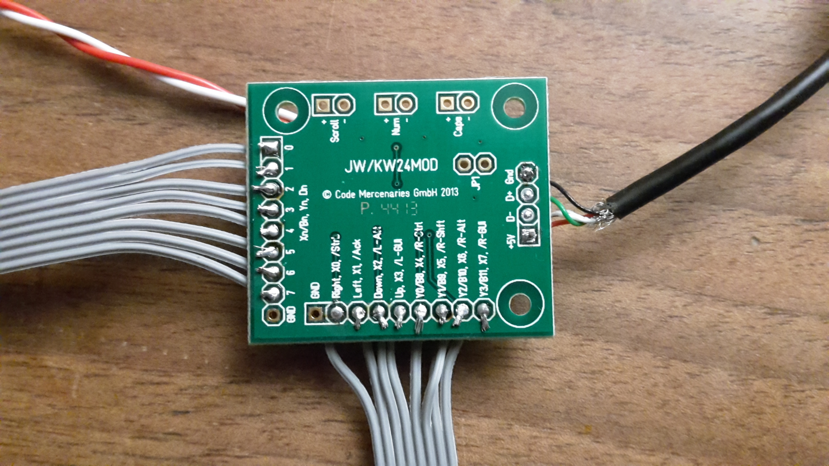
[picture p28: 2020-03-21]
images/img_chassis_27_platine_controller.jpg

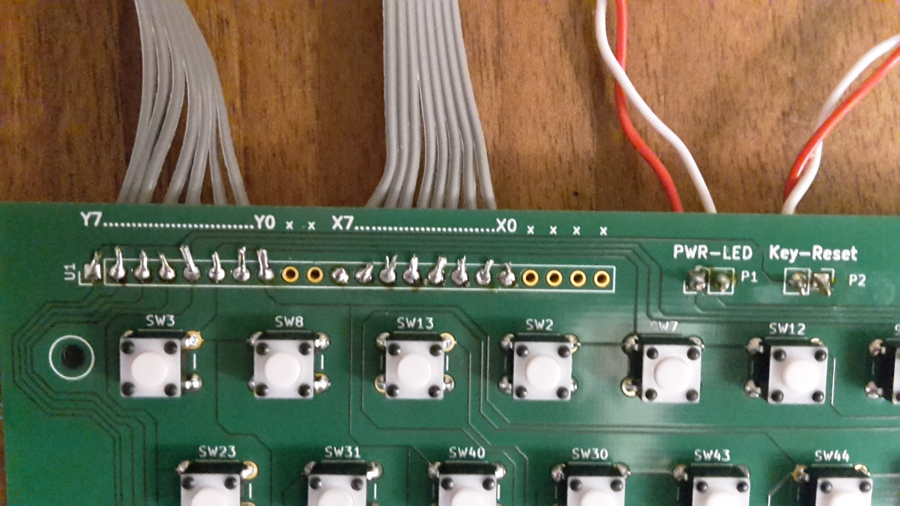
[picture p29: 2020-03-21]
images/img_chassis_32_platine_controller.jpg

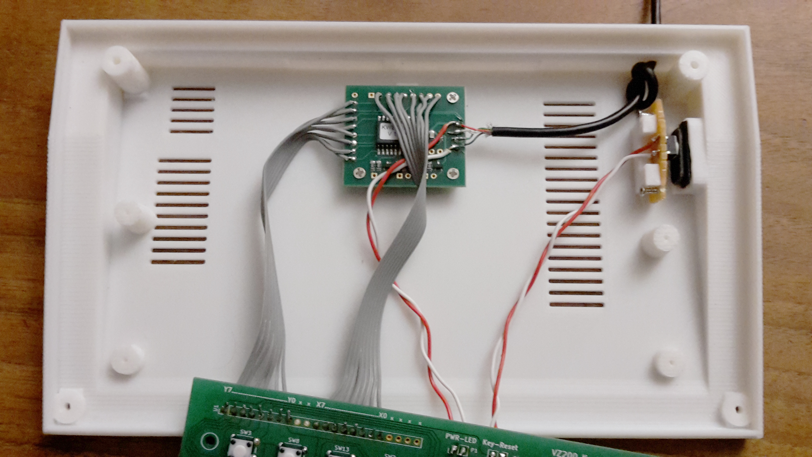
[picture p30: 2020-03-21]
images/img_chassis_36_platine_einbau.jpg

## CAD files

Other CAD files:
resources/3d-model/Monitor_5-Zoll.f3d

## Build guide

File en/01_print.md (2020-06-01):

**[BACK](README.md)**
# <a name="print">Designing and printing the Parts</a>
## 3d Model
The model has been designed with Autodesk Fusion 360.

**Word of advice**: The model of the computer case and the electronics within are sized at 70% of the original size. The STL files do reflect this already, though in the Fusion files (.3mf) the case still has it's original size. If you want to build the replica in 100% you need to adjust the ports for the keyboard controller and circuit board before having it being acit-treat. Also most likely the positon of the reset button holder needs to be adapted.

3d-Layout bottom 3d Layout bottom
3d-Layout Monitor 3d Layout Monitor

## Resources and downloads

Hardware
* [STL files on Thingiverse](https://www.thingiverse.com/thing:4415555)
* [Gerber-files for keyboards circuit board](../resources/gerber/vz200-keyboard-layout.zip)
* [Graphics for the keyboard](resources/aufkleber/Aufkleber-2x70perc.png)
* [Graphics for the logo](resources/aufkleber/logo_7x70perc_A4.png)

Software
* [JemuVZ200 Emulator V2.0](resources/releases/JemuVZ200-2.0.zip)
* VZ200 Companion App (TODO)

Documentation and Examples
* [Z80 instruction set](resources/doc/z80.pdf)
* [VZ200 Basic instruction set](resources/doc/VZ200-Basic.pdf)
* ["Hello World" (assembler) tutorial](resources/doc/tutorial/hello-world-asm-tutorial.pdf)
* ["Side Scrolling" (assembler) tutorial](resources/doc/tutorial/side-scroll-asm-tutorial.pdf)
* [Tutorial presentation (LibreOffice)](resources/doc/tutorial/VZ200-tutorial.odp)

Sources are available at:
* https://github.com/cwahlmann/vz200-remake

## Printing

The STL files exported from Fusion 360 have to be prepared and sliced for printing, we used Cura 4.x. This project already contains GCODE files for Creality Ender 3. 

We recommend printing with PLA for the VZ200 Case, the keyboard mask and the reset button. For the keyboard mat a flexible material is required, like NinjaFlex or TPU.

With the VZ200 we use white for the case, chocolade brown for the keyboard mask and any color for the keyboard mat, it will be painted later anyways.

**[BACK](README.md)**

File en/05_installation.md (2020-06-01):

**[BACK](README.md)**
# <a name="installation">Prepare and install the Emulator on the Raspberry Pi</a>

## Build the project with Gradle

From the Emulator sub directory run
```
gradle createVZ200Zip
```

You'll get a zip file with all the files required located at `build\distributions\JemuVZ200.zip`.

## Install the desktop variant of Raspbian OS

Follow the instructions on https://www.raspbian.org/ by using the image for "Raspbian Buster Desktop Lite".

## Install the emulator

Copy and extract the Zip file to the home directory of the Raspberry.
The resulting directory structure should look like this:

```
pi@raspberrypi:~ $ unzip JemuVZ200.zip
Archive:  JemuVZ200.zip
   creating: vz200/
   creating: vz200/system/
   creating: vz200/system/vz/
   creating: vz200/system/vz/rom/
  inflating: vz200/system/vz/rom/VZ.CHR
  inflating: vz200/system/vz/rom/VZBAS12.ROM
  inflating: vz200/system/vz/rom/README.txt
   creating: vz200/tape/
  inflating: vz200/tape/README.txt
   creating: vz200/tape/default/
  inflating: vz200/tape/default/README.txt
   creating: vz200/vz/
  inflating: vz200/vz/README.txt
  inflating: vz200/vz200-all.jar
  inflating: desktop-wallpaper.png
  inflating: vz200.desktop
  inflating: vz200.sh
```

## Make the start script executable 

If you built the Emulator on a Windows machine perform two additional steps:

1. Install `dos2unix`:
```
sudo apt-get install dos2unix
```

2. Convert Linefeeds to Unix Style:
```
dos2unix vz200.desktop
dos2unix vz200.sh
```

Set Execute Flag:
```
chmod +x vz200.sh
```

## Launch Emulator automatically

Copy the file `vz200.desktop` to the autostart directory:
```
mkdir ~/.config/autostart
cp vz200.desktop ~/.config/autostart
```

## Install joe Text Editor

```
sudo apt-get install joe
```
(You may also use the already installed `nano` editor)

## Install JAVA and the ALSA Sound Driver

Install OpenJDK-8 Runtime and ALSA Driver by `apt-get`:
```
sudo apt-get install openjdk-8-jre
sudo apt-get install alsa-base alsa-utils
```

Adapt the Java Sound Configuration (comment PulseAudio, uncomment DirectAudioDevice):
```
sudo joe /etc/java-8-openjdk/sound.properties
#javax.sound.sampled.Clip=org.classpath.icedtea.pulseaudio.PulseAudioMixerProvider`
#javax.sound.sampled.Port=org.classpath.icedtea.pulseaudio.PulseAudioMixerProvider
#javax.sound.sampled.SourceDataLine=org.classpath.icedtea.pulseaudio.PulseAudioMixerProvider
#javax.sound.sampled.TargetDataLine=org.classpath.icedtea.pulseaudio.PulseAudioMixerProvider

javax.sound.sampled.Clip=com.sun.media.sound.DirectAudioDeviceProvider
javax.sound.sampled.Port=com.sun.media.sound.PortMixerProvider
javax.sound.sampled.SourceDataLine=com.sun.media.sound.DirectAudioDeviceProvider
javax.sound.sampled.TargetDataLine=com.sun.media.sound.DirectAudioDeviceProvider
```
Exit the Joe Editor by STRG-K and X.

Launch Raspi Configuration and change the following Settings:
- Switch audio to headphone 
```
sudo raspi-config
```

## Install the Splash-Screen:

Edit `/boot/config.txt`:
```
sudo joe /boot/config.txt
```
Add this line:
```
disable_splash=1
```

Edit `/usr/share/plymouth/themes/pix/pix.script`:
```
sudo joe /usr/share/plymouth/themes/pix/pix.script
```
Comment these lines:
```
message_sprite = Sprite();
message_sprite.SetPosition(screen_width * 0.1, screen_height * 0.9, 10000);
my_image = Image.Text(text, 1, 1, 1);
message_sprite.SetImage(my_image);
```

Edit `/boot/cmdline.txt`:
```
sudo joe /boot/cmdline.txt
```
- Replace `console=tty1` with `console=tty3`
- and add this parameter to the end of the line:
```
splash quiet plymouth.ignore-serial-consoles logo.nologo vt.global_cursor_default=0
```

Adapt Splash Screen:
```
sudo cp ~/vz200/desktop-wallpaper-1.png /usr/share/plymouth/themes/pix/splash.png
```
Source: https://scribles.net/customizing-boot-up-screen-on-raspberry-pi/

From within the Desktop Environment change the background image to `~/vz200/desktop-wallpaper-1.png`.

## Set Volume to Max:

```
amixer sset 'Master' 65536
```
Hide Taskbar: : Right Click on Taskbar -> Bar Settings -> Advanced: Minimize Task Bar when not used + Size when minimized: 0 Pixel

Adapt HDMI Settings in /boot/config.txt: `disable-overscan=1`, `hdmi_group=1`, `hdmi_mode=3`

After a reboot the Emulator should launch in Fullscreen Mode. 

**[BACK](README.md)**

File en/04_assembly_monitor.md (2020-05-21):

**[BACK](README.md)**
# <a name="monitor">Monitor Assembly with TFT Display, Raspberry-Pi and Speaker</a>

## Required Parts

| Part | Description |
| --- | --- |
| 3D Printed parts | Case Front and Back, Front Plate (optional), holding ring for speaker, 4 rubber feet (TPU) |
| Audio Amplifier | Mini Audio Amplifier PAM8403 DC 5V |
| 3.5" Stereo plug | best use a used one since it has to be ripped apart anyway |
| Speaker | 2" / 5 cm mini speaker 3 W 4 Ohm |
| Resistors for the voltage divider : 1x 1000 kOhm, 1x 47 Ohm| This divider reduces the voltage directly at the speaker to minimize volume and amplifier noise |
| Raspberry Pi | Modell >= 3b |
| TFT-Display | JOY-iT 5“ HDMI Touchscreen Display |
| 4 screws M2 6mm | To attach the speaker within the case |
| 4 screws M2 8mm | To assemble and fasten the case |
| 4 screws M2 6mm| To attach the display |
| Double side adhesive tape | To attach the Audio Amplifier |

Attention: Other than the VZ 200 model the Monitor parts do not need to be scaled down to 70%.

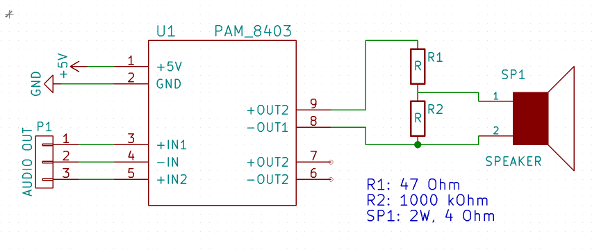
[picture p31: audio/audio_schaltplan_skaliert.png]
Audio schematics Audio Amplifier Schematics

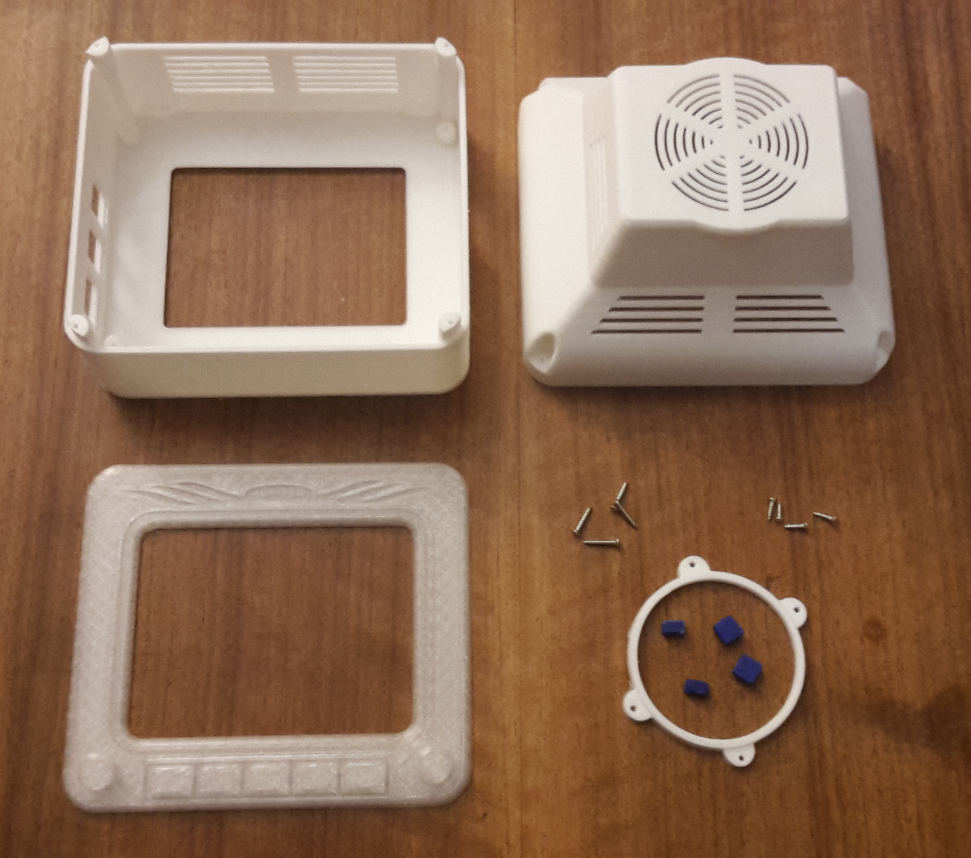
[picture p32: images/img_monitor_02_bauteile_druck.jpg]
Parts Printed

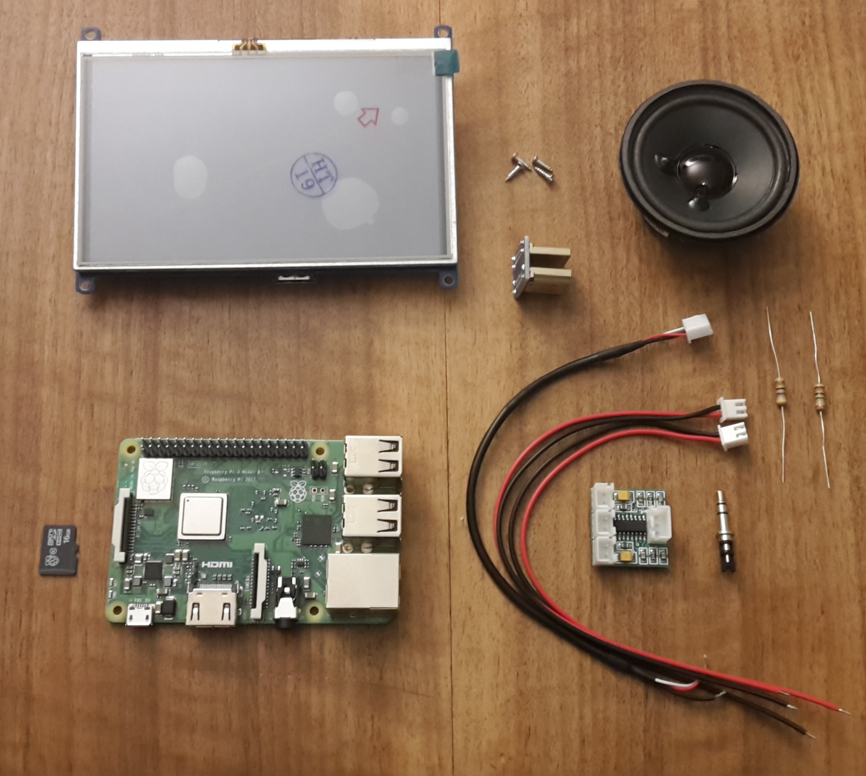
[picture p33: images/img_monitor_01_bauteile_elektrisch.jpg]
Electric parts


## Assemble the Monitor

Attach the TFT display to the GPIO Pins of the Raspberry and then connect both parts with the HDMI bridge.

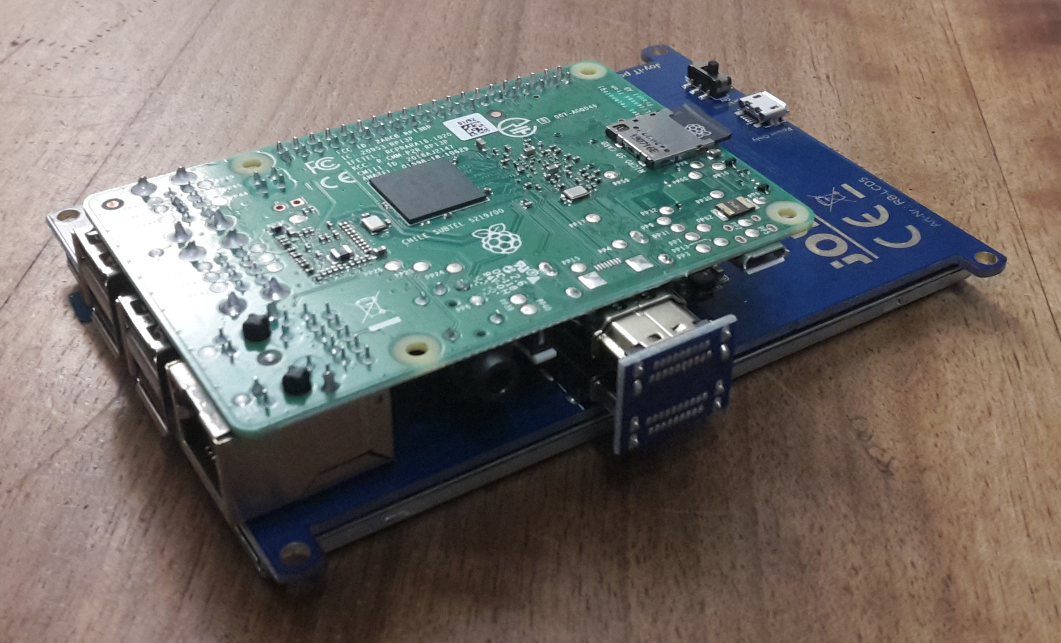
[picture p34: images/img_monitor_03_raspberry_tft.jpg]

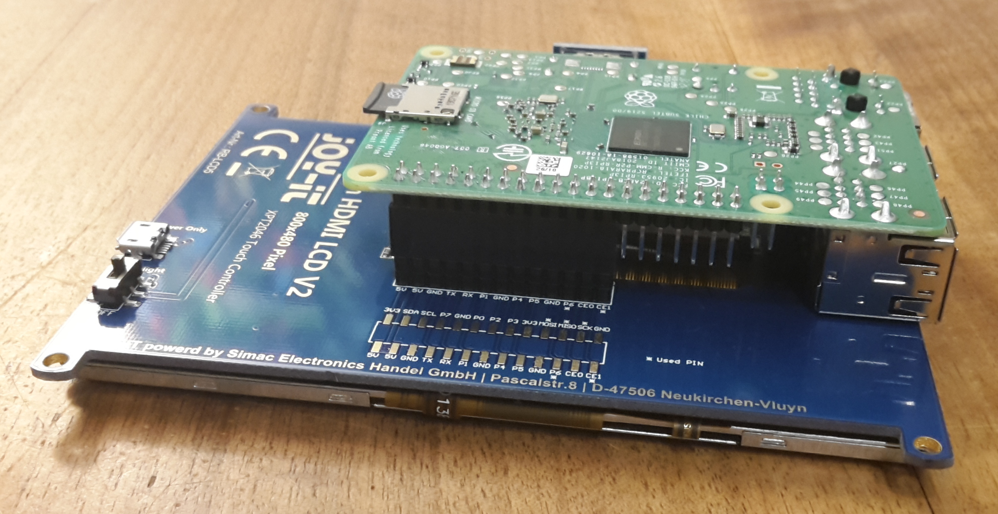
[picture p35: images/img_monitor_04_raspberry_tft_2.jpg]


The Audio Amplifier "PAM8403" amplifies the Raspberry signal quite a bit, yet also produces a lot of noise. By inserting a voltage divider and resistors both audio volume and noise will be dampened to an acceptable level.

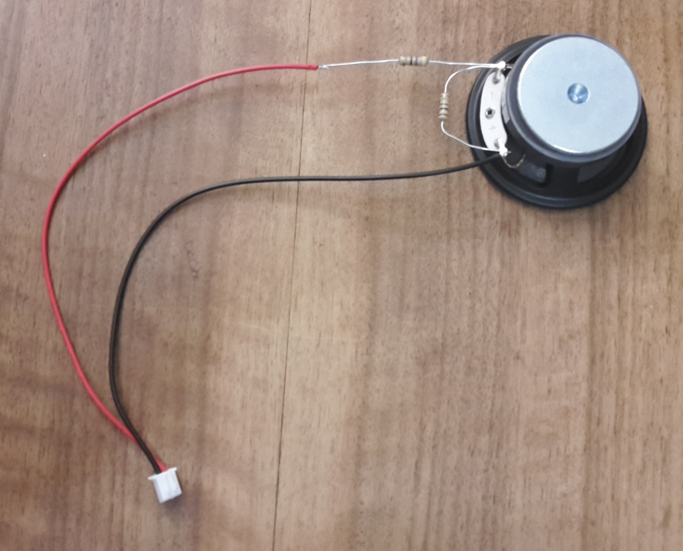
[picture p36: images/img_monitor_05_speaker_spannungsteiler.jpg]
Speaker voltage divider

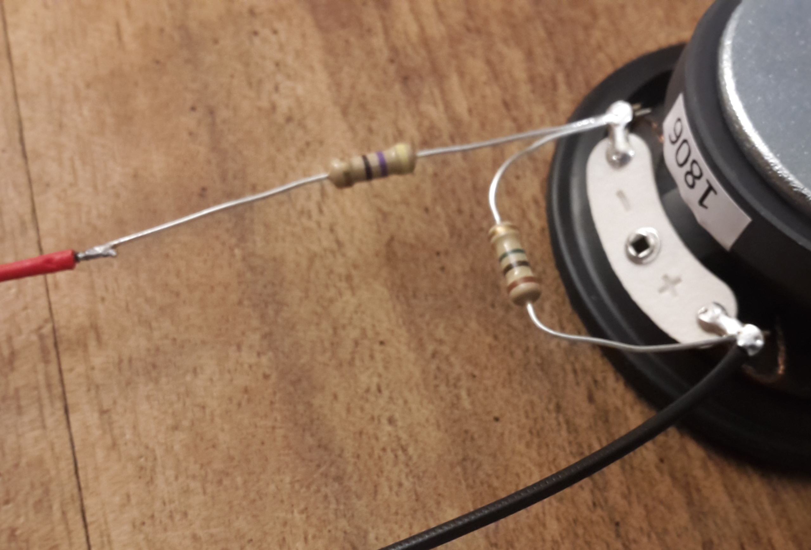
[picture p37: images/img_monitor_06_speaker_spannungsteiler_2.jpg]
Speaker voltage divider Detail


Solder the audio cable to the audio plug as shown here.

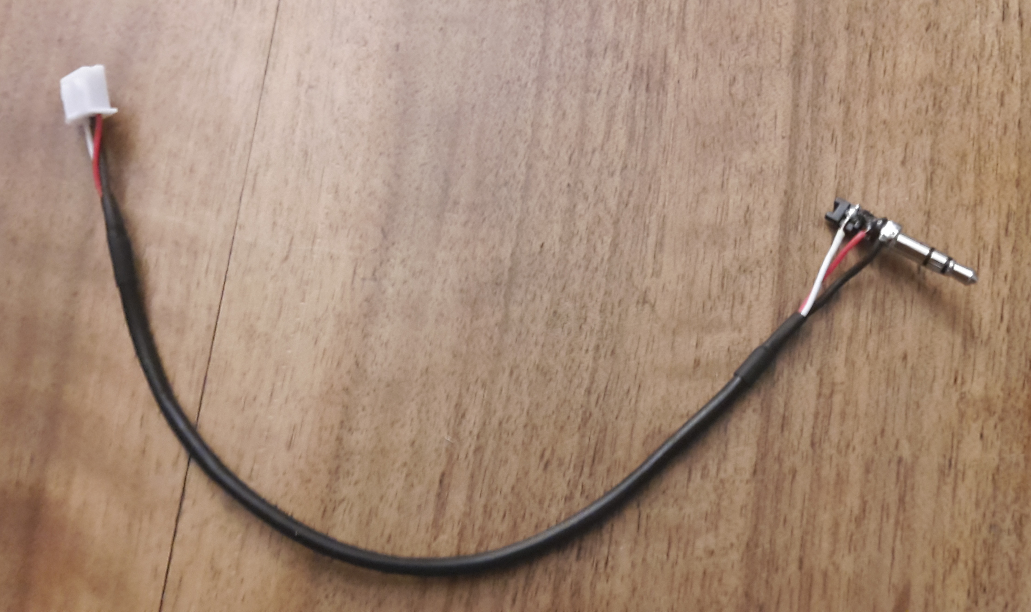
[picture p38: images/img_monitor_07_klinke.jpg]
Audio cable

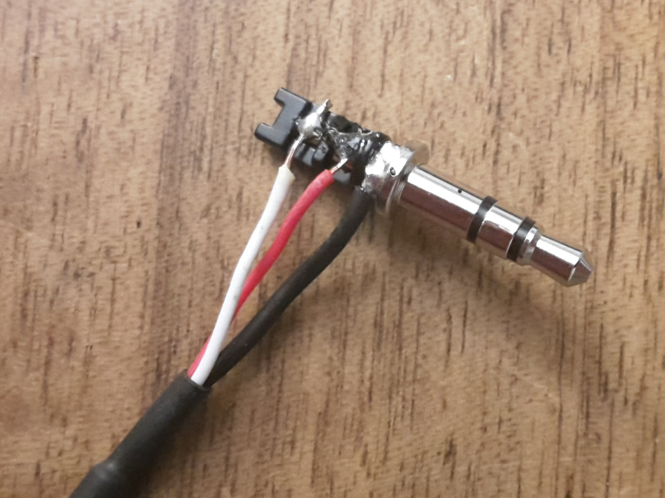
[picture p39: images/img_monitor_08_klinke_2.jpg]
Audio cable Detail


Power for the audio amplifier is taken from the GPIO pins of the TFT display (the display only utilizes a few Pins itself).

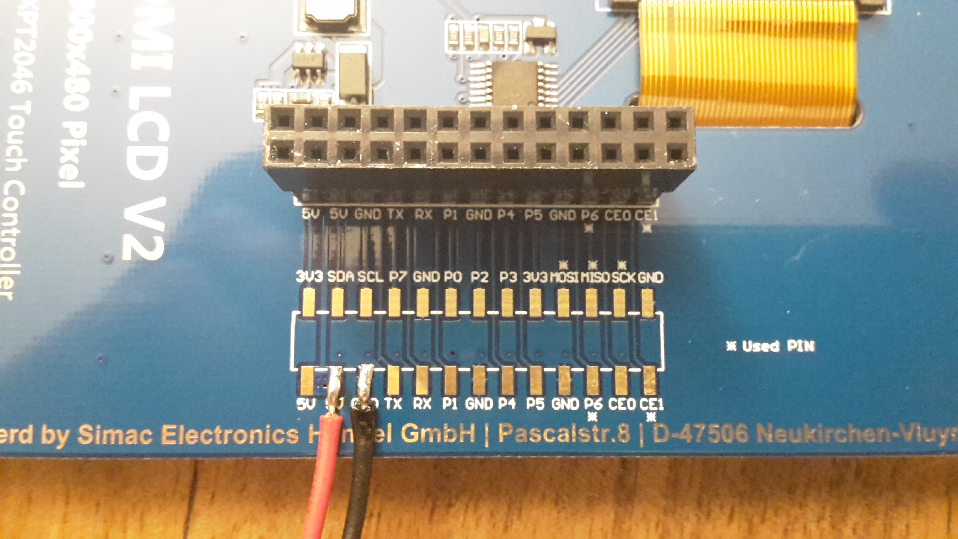
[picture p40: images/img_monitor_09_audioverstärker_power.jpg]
Solder Power Cable

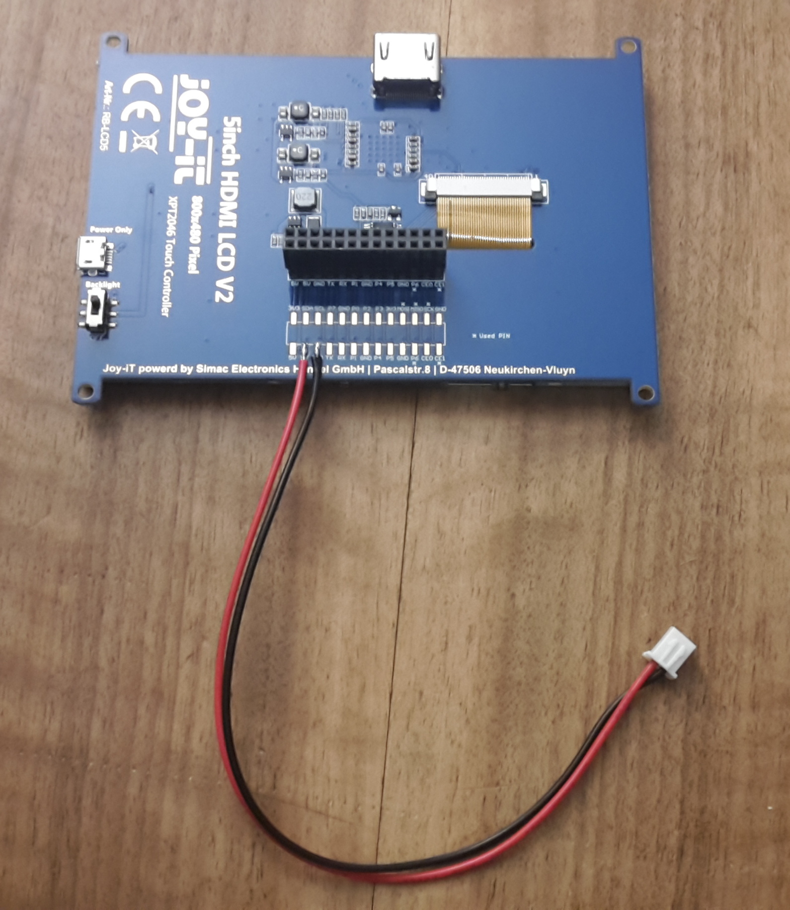
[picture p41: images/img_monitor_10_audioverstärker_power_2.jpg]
Power Cable


Here's how the completed cabeling looks like. Please pay attention to the labels on the amplifier board, those plugs must be plugged in with the correct orientation.

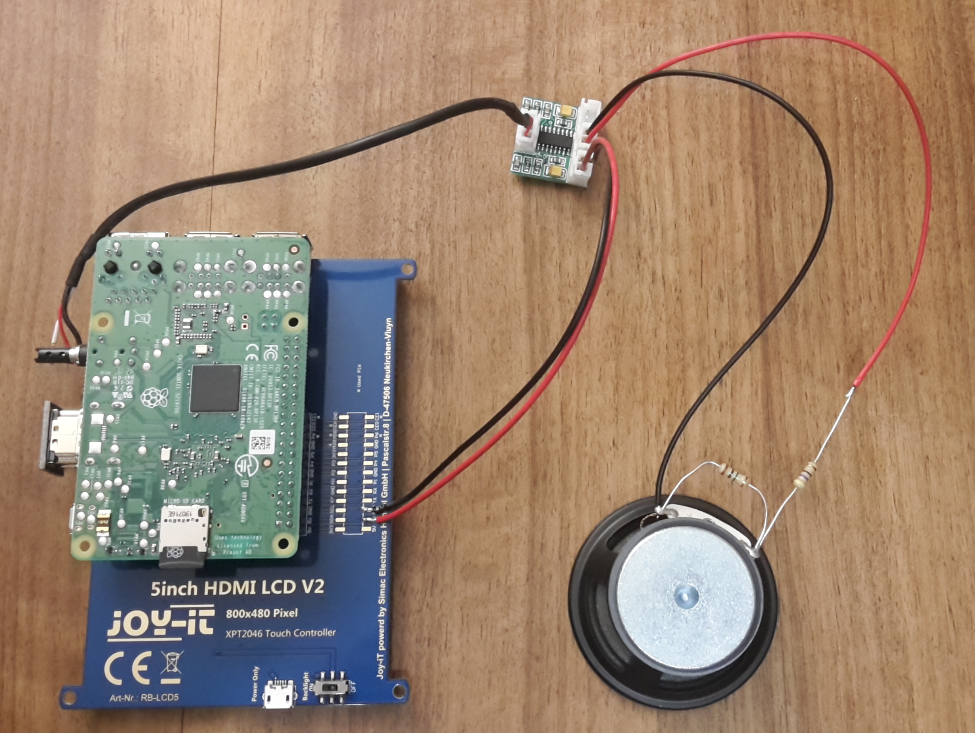
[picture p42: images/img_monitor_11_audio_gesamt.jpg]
Audio Cabeling


The VZ200 can be now run through a first test.

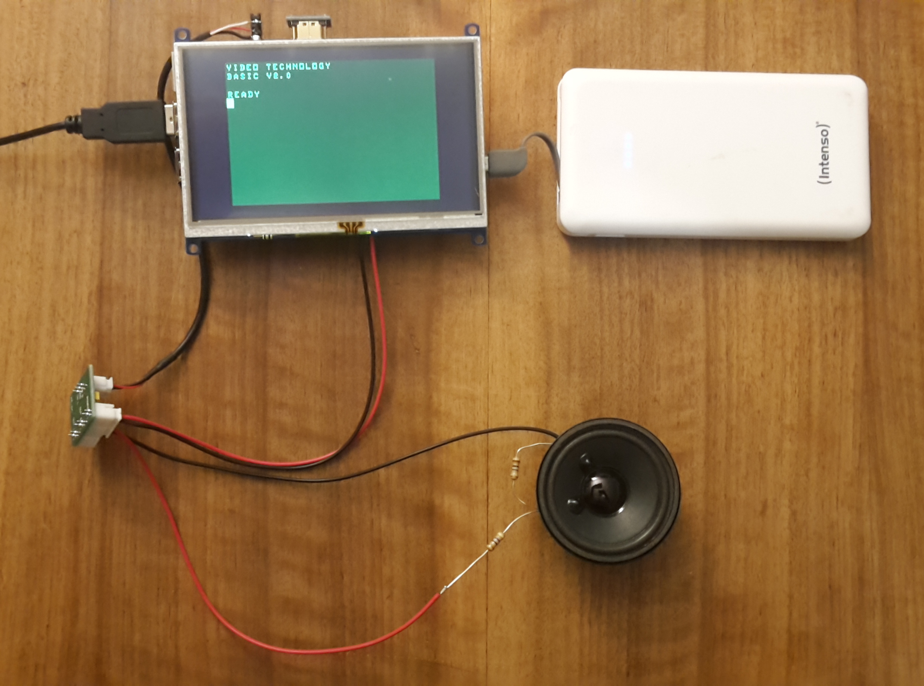
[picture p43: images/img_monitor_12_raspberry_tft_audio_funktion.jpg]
functional test


To avoid shortages, apply an isolating tape to the long resistor of the voltage divider. 

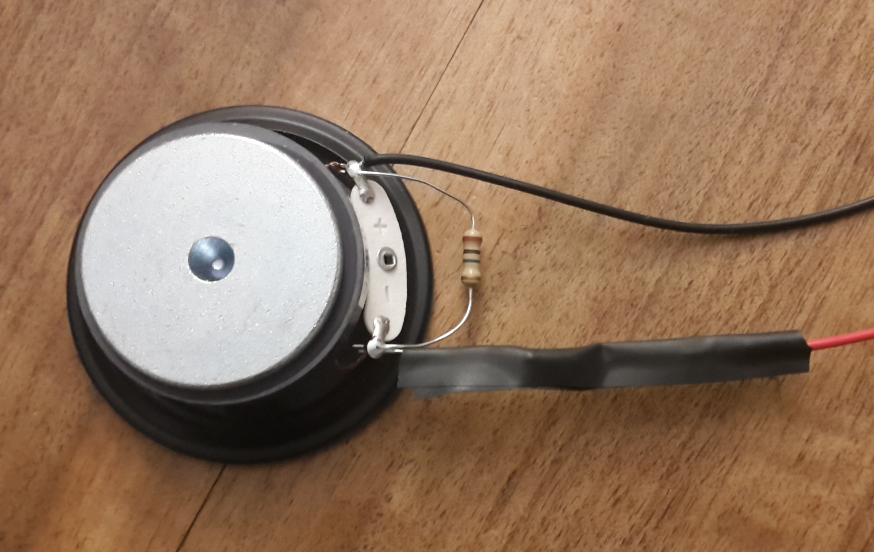
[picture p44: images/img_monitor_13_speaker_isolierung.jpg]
Speaker isolation


Attach the speaker with the 3D printed ring to the back case and fasten it with four screws. Use double side adhesive tape to attach the audio amplifier.

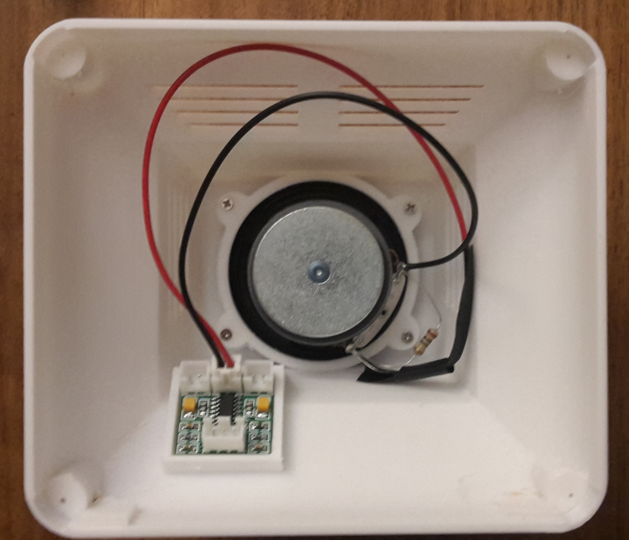
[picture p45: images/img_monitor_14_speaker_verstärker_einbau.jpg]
Monitor Speaker and Amplifier assembly


Then use another 4 screws to attach the TFT display with the plugged in Raspberry to the case front.

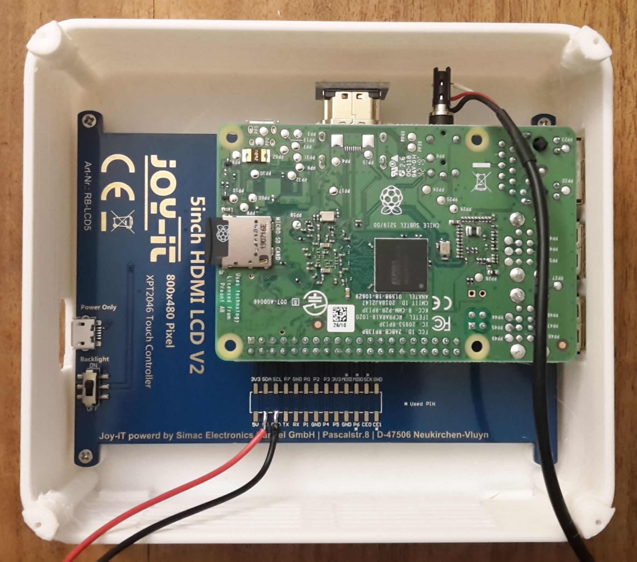
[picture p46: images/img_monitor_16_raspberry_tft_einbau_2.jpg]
Monitor TFT & Rasbpi assembly


To complete the monitor interior plug in all cables to the amplifier board and assemble the two monitor parts by fastening them with 4 screws.

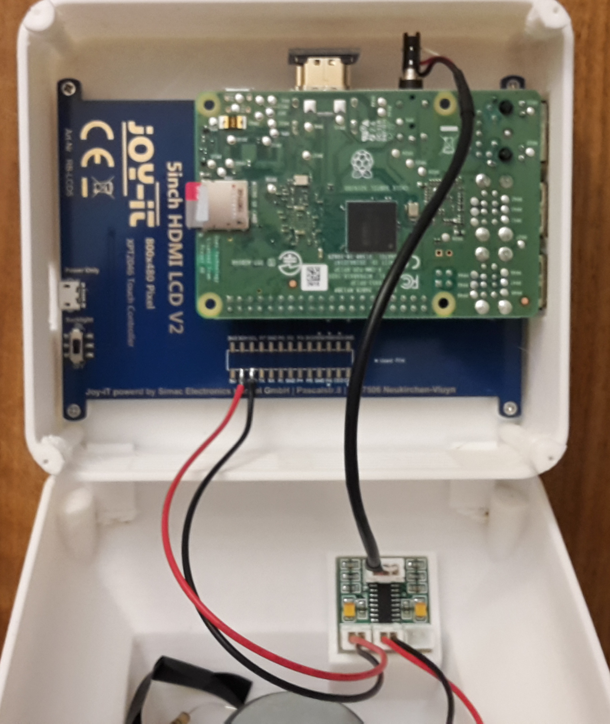
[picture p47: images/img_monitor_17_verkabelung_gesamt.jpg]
Cabeling


Glue the four monitor feet onto the bottom side of the monitor.

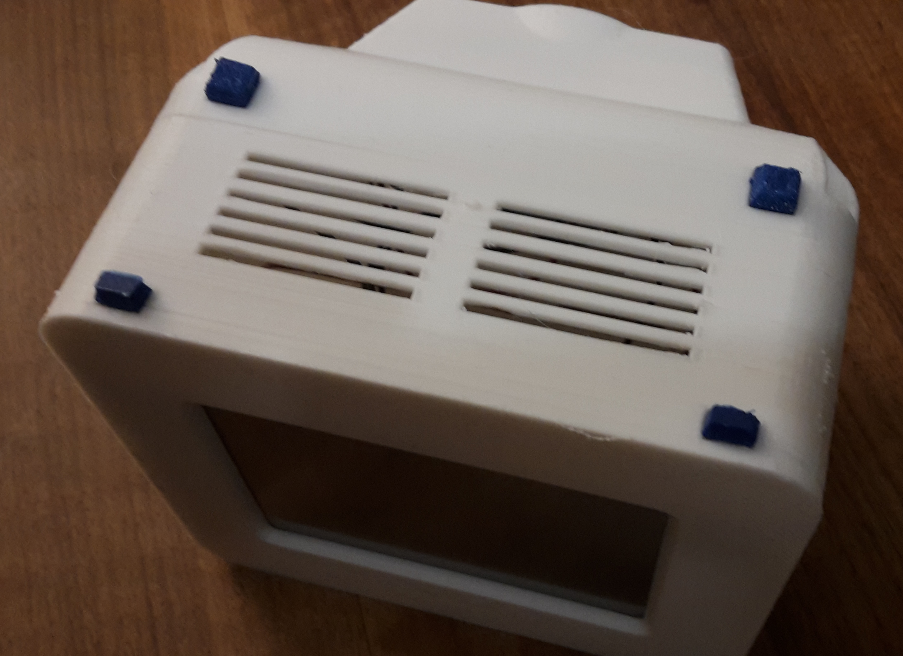
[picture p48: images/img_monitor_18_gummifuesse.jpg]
Glue rubber feet


Then either glue the seperately printed front panel to the front or design your own one. Hint: Paint the front panel beforehand to avoid compromising the TFT panel.

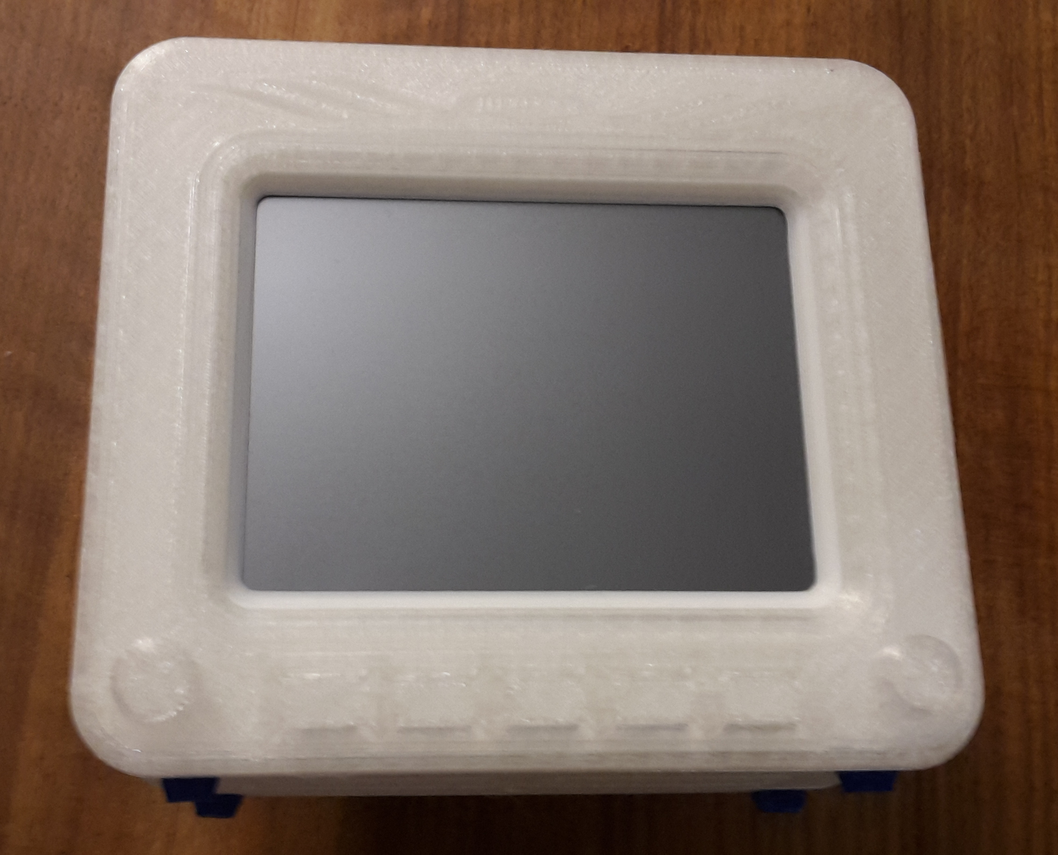
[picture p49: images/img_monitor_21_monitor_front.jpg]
Glue monitor front panel Glue monitor front pane


Now paint the rest of the monitor to your liking. If you already glued the front panel to the monitor, use masking tape to cover the TFT panel. Here is an example in a 1950er retro look;

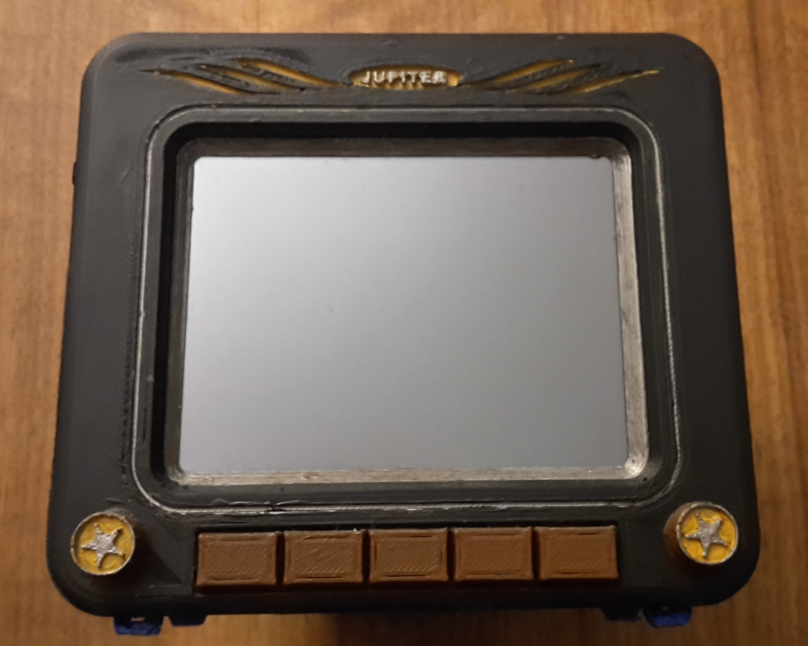
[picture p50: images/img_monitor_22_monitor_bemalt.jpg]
Painted Monitor


**[BACK](README.md)**

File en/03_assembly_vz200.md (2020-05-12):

**[BACK](README.md)**
# <a name="assemblyvz200">Assembly of the VZ200</a>

The case contains a fully functional keyboard with power LED and a reset button.

At a size of 70 % of the original VZ200 the Raspberry Pi will not fit into the case, thus it will be integrated into the monitor. The VZ200 will be connected to the Raspberry by a USB 2.0 cable.

## Required Parts

| Part | Description |
| --- | --- |
| 3D printed parts | Bottom case, Back cover, Keyboard (Frame, mask, keyboard mat), Reset Switch + Clamp |
| Printed Logo | clear, self adhesive and transparent A4 Polyester foil for ink jets |
| Printed Keys on vinyl sheet | white matt self adhesive A4 vinyl foil for ink jets |
| Printed Keyboard mask on vinyl sheet  | white matt self adhesive A4 vinyl foil for ink jets |
| Scale modeling color | e.g. EMAIL COLOR by Revell, matt 35 (skin tone) and matt 85 (brown) |
| Keyboard circuit board | available through various workshops by providing the accompanied GBR files |
| Keyboard controller | an USB keyboard controller with predefined mapping: KEYWARRIOR24_8_MODUL_KW24_8_MOD |
| USB cabel | USB cable with a 2.0 plug on one and bare wires on the other end |
| 45 micro switches | To be soldered to the keyboard cirquit board, 6x6 mm |
| 1 red LED | Power-LED, 3mm |
| 1 resistor | 150 Ohm (brown / green / brown) |
| Small piece of perforated circuit board | Used for the reset button, hole distance 2.54 mm |
| 1 micro switch | for the reset button, 6x6 mm |
| 2 x red / white wire ca. 10 cm | to connect the POWER LED and the reset button |
| 2 x 8 core flat cable ca. 10 cm | to connect keyboard controller to keyboard cirquit board |
| Isolation tape | to isolate reset button from keyboard cirquit board | 
| 7 small screws M2 5mm | to attach keyboard controller and cirquit board |
| 2 short screws M2 8mm | to attach reset button board |
| 2 short M2 5mm and 2 long M2 20mm screws | to assemble the VZ200 case |

## Attach the Logo to the back VZ200 casing
Sticker Logo

Apply the printed logo to the back case cover as shown in the picture.

Back case cover

## Assemble the keyboard
For this step you require the printed keyboard mat, the scale modeling color and the printed keyboard stickers. Do not use Airbrush or any other spraying color as this will soak the TPU and increase it's size substantially.

The keys of the mat need to be painted first with Revell Matt 35, Skin Color as a base color, then overpainted with Matt 35, brown. There is no need to paint the whole mat as it is also covered by the keyboard mask, plus this helps fitting the keys into the mask and allow them move freely.

Keyboard mat and stickers Stickers
Keyboard mat and stickers Keyboard Mat

The stickers have to be cut now.

Cutting the keyboard stickers
Cutting the keyboard stickers 2

Important notice: To achieve a rounded look cut the corners diagonally.

Cutting the keyboard stickers 3
Cutting the keyboard stickers 4
Cutting the keyboard stickers 5

The cut stickers are now applied on to the keyboard mat.

Applying the keyboard stickers
Applying the keyboard stickers

Now to prepare the keyboard mask. Have the 3d printed mask and the ink jet printed sticker ready.

Keyboard mask sticker

Now cut the holes for the keys and the Power LED.

Keyboard mask sticker cutting
Keyboard mask sticker cutting 2

Now the sticker will be applied to the mask. Carefully adjust the sticker to make sure the holes are centered around their counterparts on the mask.

There will be a small margin left so that the keys won't be hampered by the sticker.

Apply Keyboard mask sticker

Now the keyboard mat will be inserted into the mask's back and the mask inserted into the keyboard frame.

Insert Keyboard mask into the frame
Keyboard mask in frame from below

## Soldering and assemblying the electronics

The Image shows all the parts required:

Parts overview circuit board

The reset button goes onto the perforated mini board:

Reset button
Reset button 2

Connect the Reset button with the red / white wire to the keyboard circuit board.

Reset button 3

Then screw in the two short screws into the board to later attach it to the bottom case.

Reset button 4

Now connect the USB cable to the keyboard controller like shown here. 

**Attention:** The cabel needs to be put through the hole in the back of the bottom cover and knotted inside once to prevent drag on the cables.

| USB cable bare wire color | Controller port | 
| --- | --- |
| Red | +5V |
| White | D- |
| Green | D+ |
| Black | GND |

In addition solder the second red/white wire to +5V and GND for the Power LED.

| Power LED bare wire color | Controller port | 
| --- | --- |
| Redd | +5V |
| White | GND |

Keyboard Controller 2

Now solder the grey 8-core flat cable to the Controller, at the ports X0-X7 and Y0-Y7:

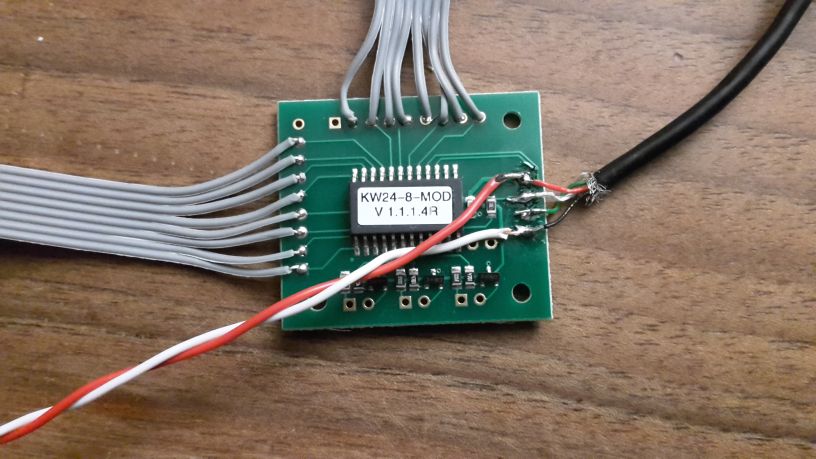
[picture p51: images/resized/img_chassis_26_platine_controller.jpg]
Keyboard Controller 3

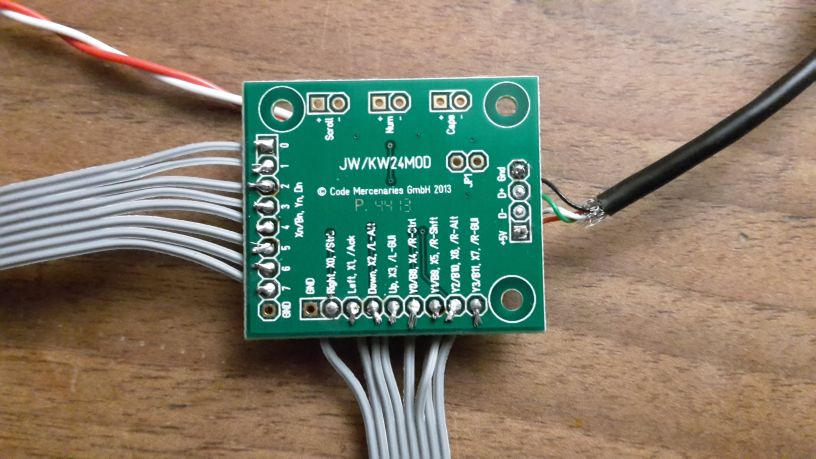
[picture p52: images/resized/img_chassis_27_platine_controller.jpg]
Keyboard Controller 4


Now add the micro switches, the Power LED and the resistor to the keyboard cirquit board:

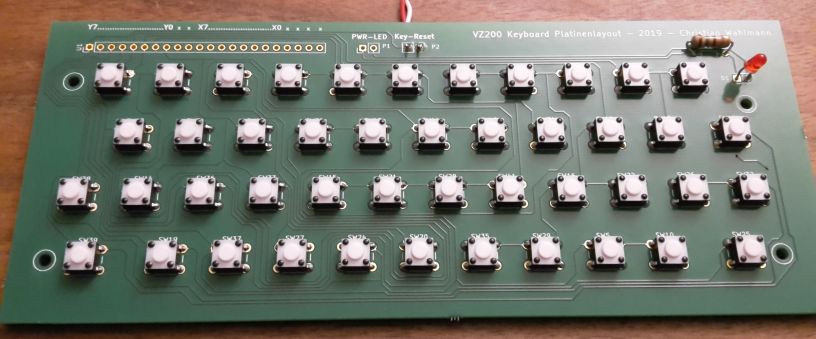
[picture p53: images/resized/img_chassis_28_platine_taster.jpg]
Circuit board micro switches


The positive pol of the LED (long leg) needs to go into the square hole of the circuit board.

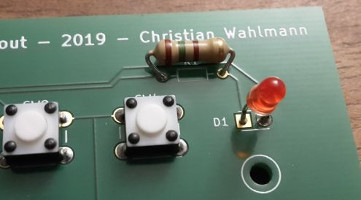
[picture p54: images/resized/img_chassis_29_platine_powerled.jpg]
Circuit Board Power LED


The orientation of the microswitches goes with the distances between the holes on the circuit board.

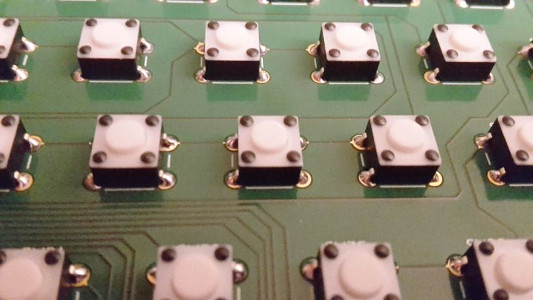
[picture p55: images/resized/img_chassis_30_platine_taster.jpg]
Circuit board micro switches 2


Now solder the red / white wire, already connected to +5V / GND of the keyboard controller, to the keyboard circuit board. 

The white bordered soldering contact represents Negative (white bare wire), the quadratic contact is Positive (red bare wire).

After this solder the two 8-core flat cables to the keyboard circuit board. Please double check for the correct orientation and connections; the soldering contacts on the keyboard circuit board are labeled x0-x7 and y0-y7 to help you.

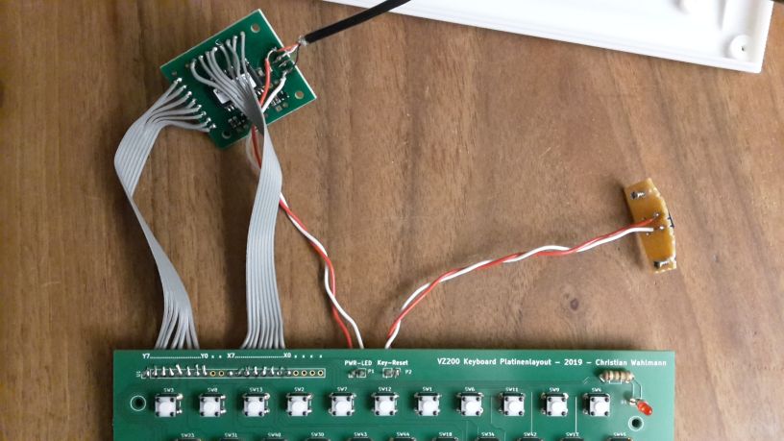
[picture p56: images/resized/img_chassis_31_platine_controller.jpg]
Circuit board Controller

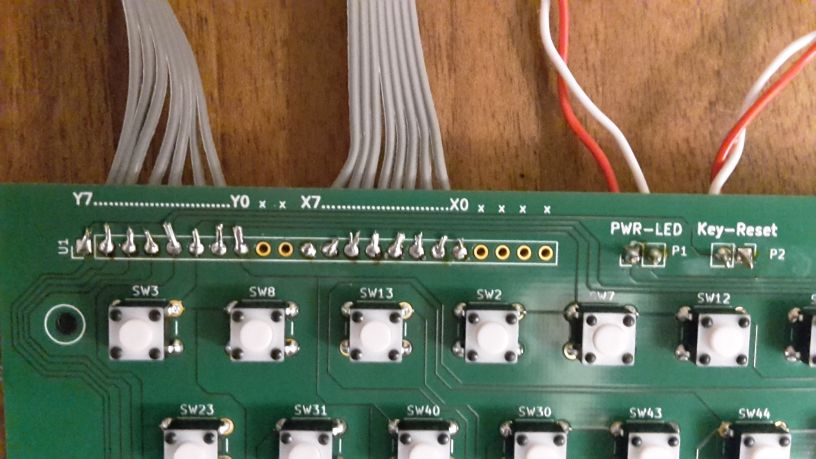
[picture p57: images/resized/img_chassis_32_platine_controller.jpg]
Circuit board Controller 2


Now insert the reset button into the case. First push the 3D printed reset button into the hole on the side and secure it with the clamp.

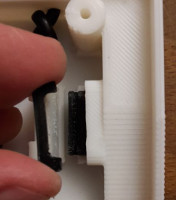
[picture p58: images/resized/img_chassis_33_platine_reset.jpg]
Circuit board reset button

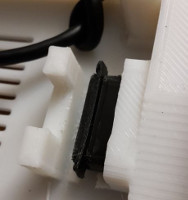
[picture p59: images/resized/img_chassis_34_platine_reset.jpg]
Circuit board reset button 2


Then add the mini board with the micro switch.

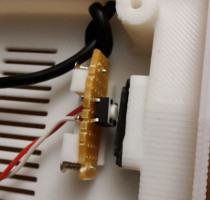
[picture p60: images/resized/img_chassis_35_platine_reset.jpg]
Circuit board reset button 3


Fasten the keyboard controller with three short screws to the bottom case.

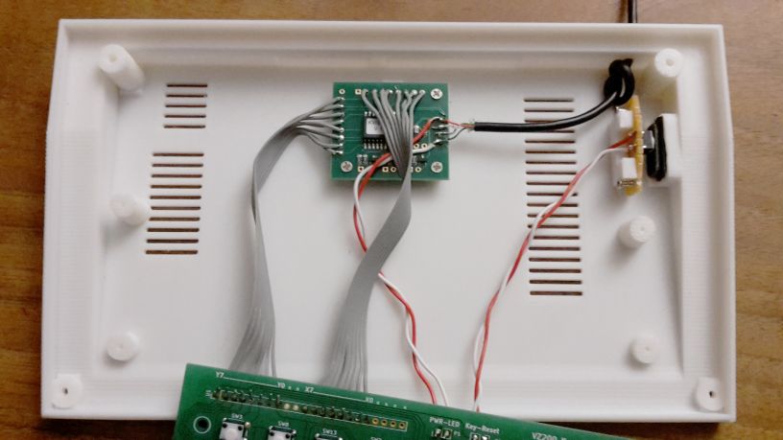
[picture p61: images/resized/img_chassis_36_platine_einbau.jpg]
Circuit board assembly


Cover the reset switch with a small piece of isolation tape to avoid contact between the screw and the keyboard cirquit board.

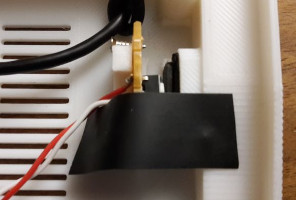
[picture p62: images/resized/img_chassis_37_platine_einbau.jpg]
Circuit board assembly 2


Attach the cirquit board to the bottom case with four short screws.

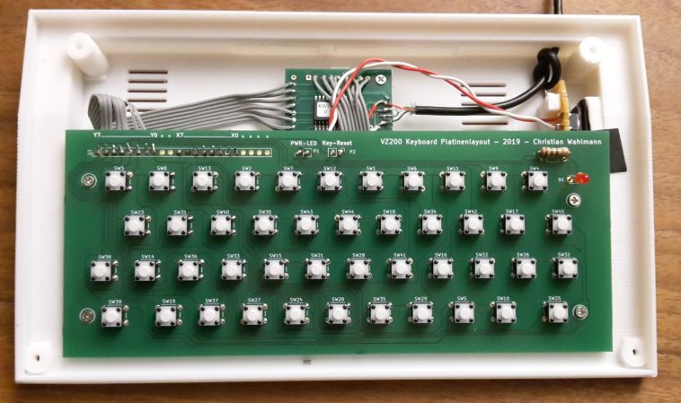
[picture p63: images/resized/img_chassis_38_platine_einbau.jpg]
Circuit board assembly 3


Last but not least add the keyboard frame and the back cover and fasten them to the bottom case with two long and to short screws.

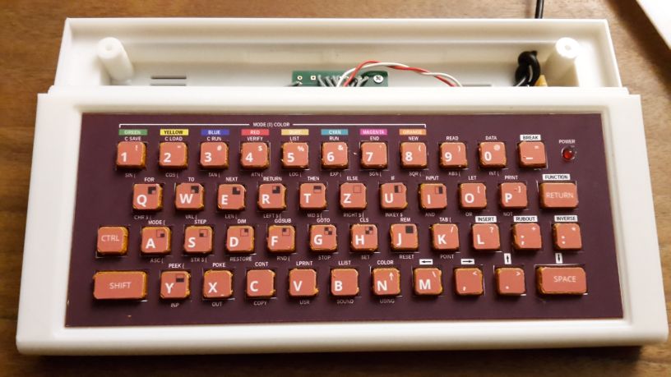
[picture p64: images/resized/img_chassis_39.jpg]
Chassis Assembly

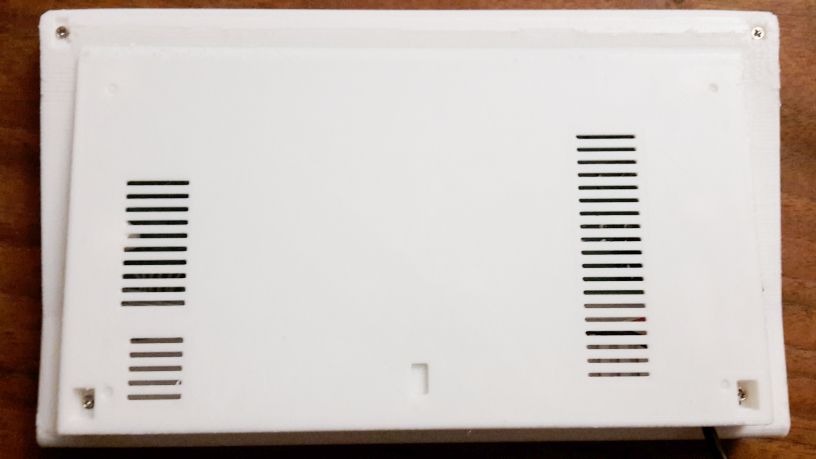
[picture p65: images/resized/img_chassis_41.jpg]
Chassis Assembly 2

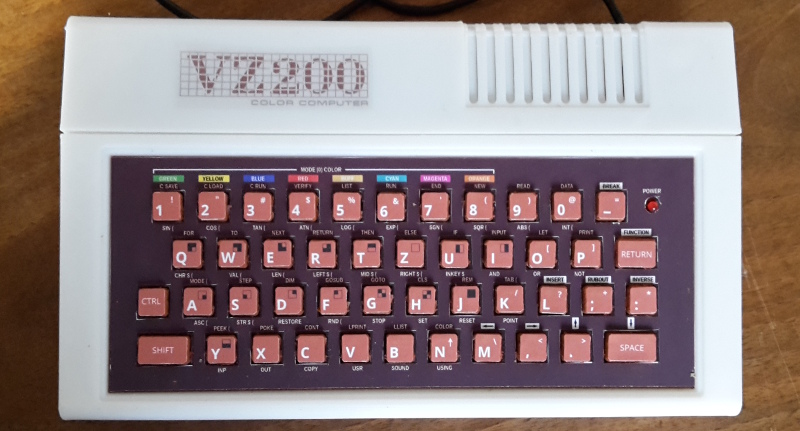
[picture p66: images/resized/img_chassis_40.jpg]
Chassis Assembly 3


Congratulations, You have just completed your first VZ200 replica!

The JEmu emulator can be run on a Raspberry Pi 3b+ or higher or on a PC. Plug in the VZ200 as an USB keyboard in either case.

Important notice: In case the keyboard produces more than one keypress unintentionally or shows multiple different chars at once on one keypress, there most likely is a shortcut between one or more of the micro switches. This may happen occasionally if some of the very fine threads of the wires have not been soldered correctly and produce a bridge to another micro switch. 

To get rid of those issues we recommend inspecting the circuit board under a strong lamp from every angle, probably utilizing a magnifying glas. Even the most tiny threads will light up eventually and you'll be able to cut and remove them. Focus on the keys producing erroneous results.

Another source for errors: Cold soldering contacts (this applies to the whole project). These are easily spotted by their slightly matt and milky surface. Please resolder these.

**[BACK](README.md)**

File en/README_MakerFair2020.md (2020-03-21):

zur deutschen Seite

# vz200-remake
A remake of the VZ200 Color Computer (Vtech / Dick Smith 1983)

Prototyp VZ200 - 70%

# *VZ200-remake* at the Makerfaire-Ruhr

    We are pleased being part of the program of the Makerfair-Ruhr in Dortmund.
    
    To our regret the fair has been cancelled like many other events due to the Corona crisis going on,
    though we do understand the reasoning behind this. Health comes first.  

    To make up for it we now will put online all the material we meant to present to you
    at the makerfaire. May some of you spend happy hours reprinting,
    souldering and assembling the VZ200! 
        
    If there is any chance for the faire to be held later this year, you most
    likely will find us there ;-)

Here you already find the video, that should have been running in the background of the faire:

VZ200 Presentation Makerfaire (https://www.youtube.com/watch?v=7TxQ1y71ufA)

makerfaire-ruhr.com/maker2020 (https://www.makerfaire-ruhr.com/meet-the-makers)

Basic Programming
Charset
the hunter - bit by a bat

# that's waiting for you:

* design- and printdata for ...

... a VZ200 Color Computer 70% of the original size

... a monitor with built-in TFT-display, Raspberry PI and speaker

* circuit board design and .gbr files for a full functional keyboard
* VZ200 emulator (based on 'jemu': http://jemu.winape.net) with datasette-emulation and REST-interface
* VZ200 Companion App to control your VZ200 from remote by the REST-interface
* list of all needed parts
* detailled building and installation instruction

# Impressions from the construction site
 
The VZ200 should have a fully functional rubber keyboard. We solved this with a self-designed circuit board with push buttons, on which the printed mat with rubber buttons lies, connected to an USB keyboard controller. In pieces:

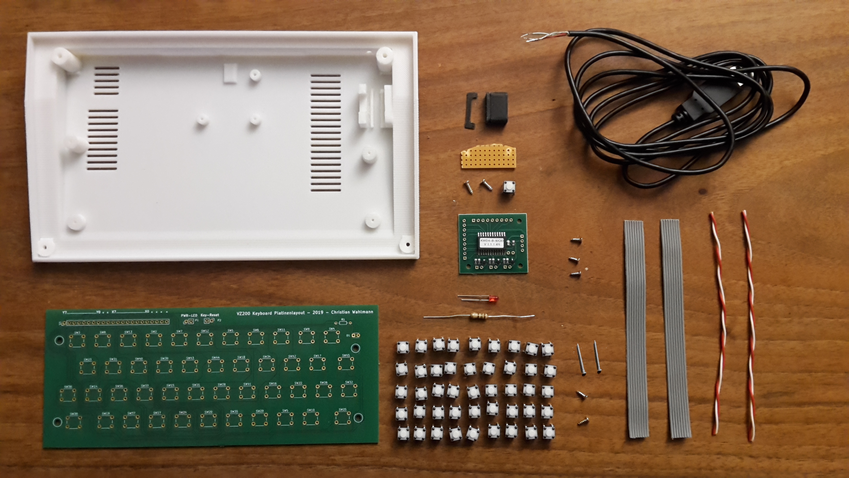
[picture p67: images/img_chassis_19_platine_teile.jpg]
img_chassis_19_platine_teile keyboard in pieces


The emulator runs on a Raspberry PI 3b combined with a 5 inch HDMI display. A small amplifier chip provides the sound. Everything is built into a monitor housing.

img_monitor_12_raspberry_tft_audio_funktion VZ200 auf dem Raspi mit Sound

Here is a picture of the first finished model. The source for the game is available at [the-hunter.asm](../examples/the-hunter.asm), or get the .VZ-file [thehunter.vz](../examples/thehunter.vz)

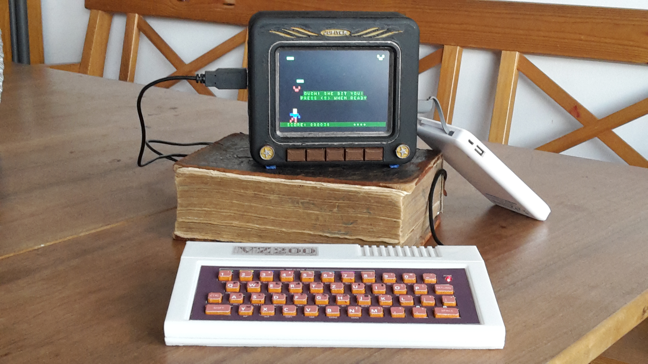
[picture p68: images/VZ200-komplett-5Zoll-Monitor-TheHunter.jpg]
VZ200-komplett-5Zoll-Monitor-TheHunter das erste fertige Modell


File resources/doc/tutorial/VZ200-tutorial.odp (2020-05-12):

## VZ200 Basic Tutorial „hello-world“

BASICPROGRAMM HELLO-WORLD.BAS:

10 CLS

20 FOR I=0 TO 511

30 POKE 28672+I, I AND 255

40 NEXT

50 GOTO 50

RUN

## VZ200 Basic Tutorial „hello-world“

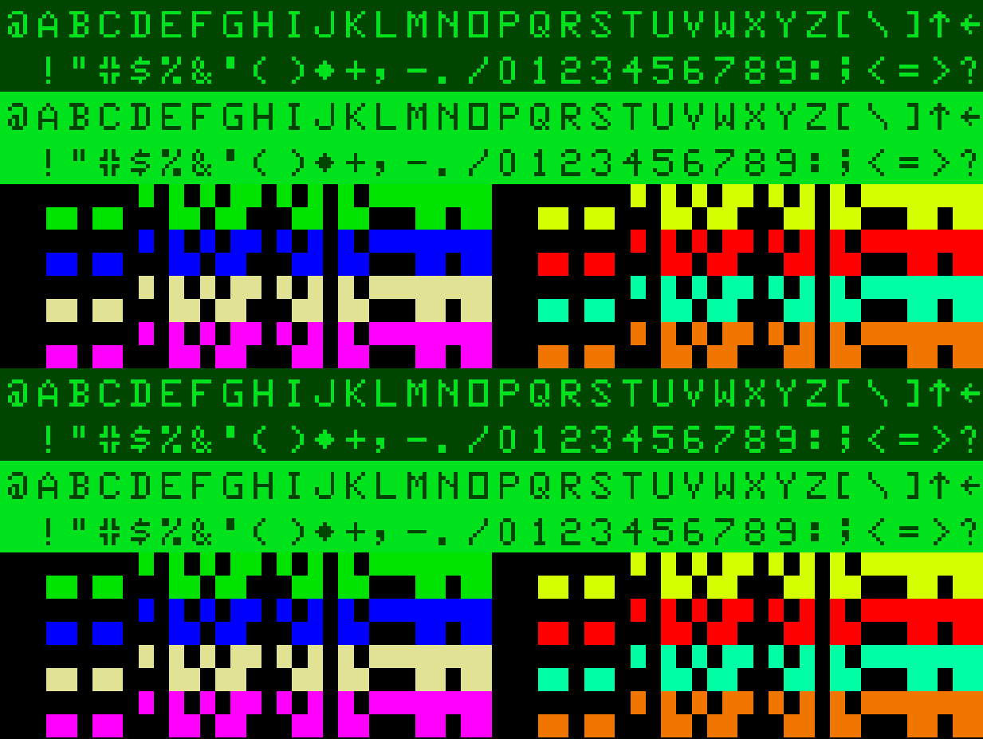
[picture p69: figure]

## VZ200 Basic & Assembler Tutorial „hello-world“

ASSEMBLERPROGRAMM HELLO-WORLD.ASM:

.org 0x7200 // Programm in Grafikspeicher laden

.run 0x7200 // und dort auch starten

.def screen: 0x7000 // Bildschirmspeicheradresse

LD HL, screen: // Bildschirmspeicheradresse in HL

LD BC, 0x0200 // Zähler = Länge des Bildschirmspeichers

// im Textmodus

LD D, 0x00 // aktuelles Zeichen beginnend mit @

loop: // Schleife

LD (HL), D // Zeichen in Bildschirmspeicher laden

INC HL // nächste Adresse

INC D // nächstes Zeichen

DEC BC // Zähler runterzählen

LD A, B // Test, ob Zähler = 0

OR C

JR NZ, loop: // Nein? weiter in der

RET // Programm beenden

## VZ200 Basic & Assembler Tutorial „hello-world“

KODIERUNG IN Z80-MASCHINENCODE:

ASM | HEX | DEZIMAL |

LD HL,0x7000 | 21 00 70 | 33, 0, 112 | Bildschirmspeicheradresse
| | | in HL

LD BC,0x0200 | 01 00 02 | 1, 0, 2 | Zähler = Länge des
| | | Bildschirmspeichers im

| | | Textmodus

LD D,0x00 | 16 00 | 22, 0 | aktuelles Zeichen

| | | (beginnend mit @)

LD (HL),D | 72 | 114 | Schleife; Zeichen in Bild-

| | | schirmspeicher laden

INC HL | 23 | 35 | nächste Adresse

INC D | 14 | 20 | nächstes Zeichen

DEC BC | 0b | 11 | Zähler runterzählen

LD A,B | 78 | 120 | Test, ob Zähler = 0

OR C | b1 | 177 |

JR NZ, -8 | 20 f8 | 32 248 | Schleife

RET | c9 | 201 | Programm beenden

## VZ200 Basic & Assembler Tutorial „hello-world“

BASIC-PROGRAMM:

10 REM --- HALLO-WELT-ASSEMBLER ---
20 A = 28672 + 512: REM *** HIRES-SCREEN-MEM
30 READ B:REM *** BYTE-LESEN
40 IF B > 255 THEN 80:REM *** FERTIG?
50 POKE A, B:REM *** BYTE-SCHREIBEN
60 A=A+1
70 GOTO 30
80 REM *** USR-POINTER-SCHREIBEN
90 POKE 30862, 0
100 POKE 30863, 114: REM 72
120 X=USR(X):REM *** MASCHINEN-PROGRAMN-STARTEN
130 GOTO 130
1000 DATA 33, 0, 112, 1, 0, 2, 22, 0,
1010 DATA 114, 35, 20, 11, 120, 177, 32, 248, 201
1020 DATA 999

RUN

## VZ200 Basic & Assembler Tutorial „hello-world“

## VZ200 Basic & Assembler Tutorial „side-scrolling“

| | | | | | | | | | | | | | | | | | | | | | | | | | | | | | | X
| | | | | | | | | | | | | | | | | | | | | | | | | | | | | | | X
| | | | | | | | | | | | | | | | | | | | | | | | | | | | | | | X
| | | | | | | | | | | | | | | | | | | | | | | | | | | | | | | X
| | | | | | | | | | | | | | | | | | | | | | | | | | | | | | | X
| | | | | | | | | | | | | | | | | | | | | | | | | | | | | | | X
| | | | | | | | | | | | | | | | | | | | | | | | | | | | | | | X
| | | | | | | | | | | | | | | | | | | | | | | | | | | | | | | X
| | | | | | | | | | | | | | | | | | | | | | | | | | | | | | | X
| | | | | | | | | | | | | | | | | | | | | | | | | | | | | | | X
| | | | | | | | | | | | | | | | | | | | | | | | | | | | | | | X
| | | | | | | | | | | | | | | | | | | | | | | | | | | | | | | X
| | | | | | | | | | | | | | | | | | | | | | | | | | | | | | | X
| | | | | | | | | | | | | | | | | | | | | | | | | | | | | | | X
| | | | | | | | | | | | | | | | | | | | | | | | | | | | | | | X
| | | | | | | | | | | | | | | | | | | | | | | | | | | | | | | X

## VZ200 Basic & Assembler Tutorial „side-scrolling“

ASSEMBLERPROGRAMM SIDE-SCROLL.ASM:

.org 0x7200

.run 0x7200

.def screen: 0x7000

LD HL, screen: // HL = Bildschirm

// Startadresse

LD DE, screen: // DE = Bildschirm // Startadresse+1

INC DE

LD BC, 0x01ff // BC = Zähler

loop: // Schleife 1

LD A, (DE) // Zeichen aus DE
// laden

LD (HL), A // und nach HL
// schreiben

INC HL // Adresspointer

// erhöhen

INC DE

DEC BC // Zähler - 1

LD A, B // Zähler = 0 ?

OR C

JR NZ, loop: // nein, weiter

LD HL, screen: // HL = Bildschirm

// Startadresse

LD DE, 0x0020 // DE = Zeilenlänge

ADD HL, DE // HL+Zeilenlänge

// -1 = Ende der

// 1. Zeile

DEC HL

LD B, 0x10 // B = Zähler für

// 16 Zeilen

LD A, 0x20 // A = Leerzeichen

loop2: // Schleife

LD (HL), A // Leerzeichen

// schreiben

ADD HL, DE // nächste Zeile

DEC B // Zähler - 1

JR NZ, loop2: // weiter, solange
// Zähler != 0

RET // Ende

## VZ200 Basic & Assembler Tutorial „side-scrolling“

KODIERUNG IN Z80-MASCHINENCODE:

HEX | DEZIMAL | ASSEMBLER |

21 00 70 | 33, 0, 112 | LD HL,0x7000 | HL = Bildschirm

| | | Startadresse

11 00 70 | 17, 0, 112 | LD DE,0x7000 | DE = Bildschirm

| | | Startadresse + 1

13 | 19 | INC DE |

01 ff 01 | 1, 255, 1 | LD BC,0x01FF | BC = Zähler

1a | 26 | LD A,(DE) | Schleife 1; Zeichen aus

| | | DE laden

77 | 119 | LD (HL),A | und nach HL schreiben

23 | 35 | INC HL | Adresspointer erhöhen

13 | 19 | INC DE |

0b | 11 | DEC BC | Zähler - 1

78 | 120 | LD A,B | Zähler = 0 ?

b1 | 177 | OR C |

20 f7 | 32, 247 | JR NZ, -9 | nein, weiter

21 00 70 | 33, 0, 112 | LD HL,0x7000 | HL = Bildschirm

| | | Startadresse

11 20 00 | 17, 32, 00 | LD DE,0x0020 | DE = Zeilenlänge

19 | 25 | ADD HL,DE | HL + Zeilenlänge - 1 =

| | | Ende der 1. Zeile

2b | 43 | DEC HL |

06 10 | 6, 16 | LD B,0x10 | B = Zähler für 16 Zeilen

3e 20 | 62, 32 | LD A, 0x20 | A = Leerzeichen

77 | 119 | LD (HL), A | Schleife 2; Leerzeichen

| | | schreiben

19 | 25 | ADD HL,DE | nächste Zeile

05 | 5 | DEC B | Zähler - 1

20 fb | 32, 251 | JR NZ, -4 | weiter, solange Zähler!=0

c9 | 201 | RET | Ende

## VZ200 Basic & Assembler Tutorial „side-scrolling“

BASIC-PROGRAMM:

10 REM *** SCROLL-LEFT-DEMO ***

20 CLS:COLOR,0

30 PRINT"***** SIDE SCROLLING DEMO *****"

40 PRINT@160," <W> UP"

50 PRINT" <S> DOWN"

50 PRINT" <X> EXIT"

40 PRINT@320," !! TRY TO AVOID STARS !! "

60 PRINT@480," LOADING ASSEMBLER ...";

80 GOSUB 900:SOUND 0,5

90 CLS:COLOR,1:P=165:Q=165

100 REM *** GAME LOOP ***

110 PRINT@Q," ";

120 X=USR(X)

125 IF PEEK(28672+P+3)<>32 THEN PRINT@P-2,"%=#$!#";:GOTO140

130 PRINT@P,">=-";

140 POKE 28672+31+32*(RND(16)-1), 42

150 Q=P

170 B$=INKEY$

180 IF P>=32 AND B$="W" THEN P=P-32

190 IF P<480 AND B$="S" THEN P=P+32

200 IF B$<>"X" THEN 100

210 CLS:COLOR,0

220 END

900 REM *** ASM-PROGRAMM-INSTALLIEREN ***

910 A = 28672 + 512

920 A1 = INT(A / 256): A0 = A - 256 * A1

930 POKE 30862, A0:POKE 30863, A1

940 READ B:REM *** BYTE-LESEN

950 IF B > 255 THEN RETURN:REM *** FERTIG?

960 POKE A, B:REM *** BYTE-SCHREIBEN

970 A=A+1

980 GOTO 940

1000 DATA 33, 0, 112, 17, 0, 112, 19, 1

1010 DATA 255, 1, 26, 119, 35, 19, 11, 120

1020 DATA 177, 32, 247, 33, 0, 112, 17, 32

1030 DATA 00, 25, 43, 6, 16, 62, 32, 119

1040 DATA 25, 5, 32, 251, 201

1020 DATA 999

READY

RUN

## VZ200 Basic & Assembler Tutorial „side-scrolling“

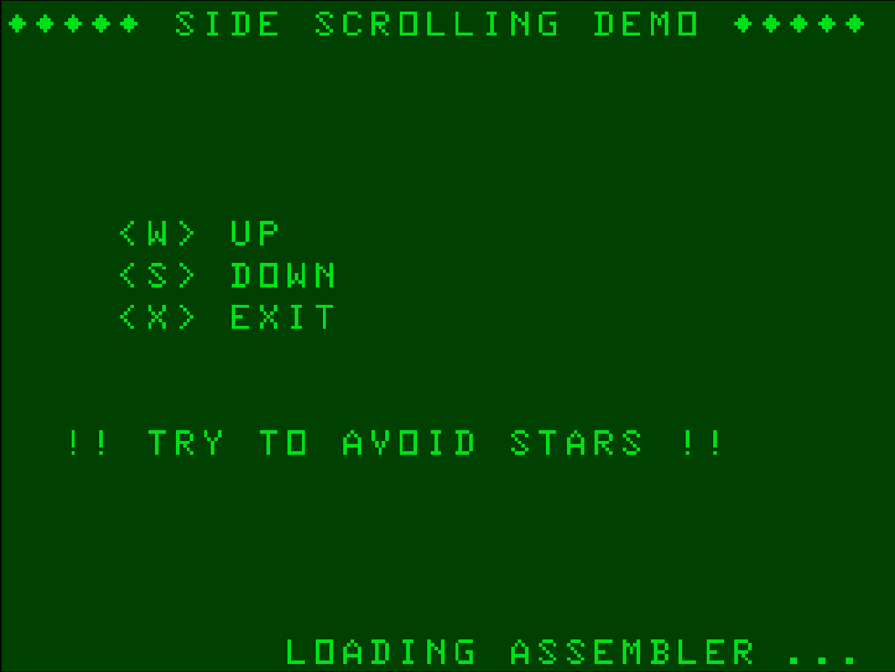
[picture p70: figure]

## VZ200 Basic & Assembler Tutorial „side-scrolling“


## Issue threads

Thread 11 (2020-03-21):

Doku Bauanleitung von vz200 nach vz200-remake portieren

cwahlmann, 2020-03-21:
Die Dokumentation der Bauanleitung im Repo vz200 soll nach vz200-remake portiert werden.

- Doku Software-Installation und Emulator-Dokumentation sollen in vz200 verbleiben, bis die Arbeiten am Emulator abgeschlossen sind

- [x] Text und Bilder ins öffentliche Repo verschieben
- [x] Texte ggf. sprachlich überarbeiten
- [x] Texte ggf. auf mehrere Dateien aufteilen
- [x] Englische Übersetzung

cwahlmann, 2020-03-21:
Kannst du hiermit vielleicht schon mal anfangen? Wenn ich den Rest-Service des Emulators fertig und eingecheckt habe, und du dann mit der Companion-App dran wärst, könnte ich hier weitermachen.

kashban, 2020-03-21:
Ja, mache ich im Laufe des Wochenendes.

cwahlmann, 2020-03-24:
Hi! Unter "Platinendesign und -produktion" sind zwei Bilder kaputt.

kashban, 2020-03-26:
Ist behoben

cwahlmann, 2020-04-05:
Ich mach mal weiter und teile die Dokumentation in Unterkapitel auf

kashban, 2020-05-11:
Ich bin an der Übersetzung dran.

kashban, 2020-06-01:
Ist übersetzt.

Closed 2020-06-01.

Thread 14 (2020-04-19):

Graphic additions

oss003, 2020-04-19:
Hi, did you implement some graphics additions like the German Mod or the Australian mod?
If so, then I have a few files for testing, using 32KB RAM expansion and a German or Australian mod
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
[MPAGD_GAMES.zip](https://github.com/cwahlmann/vz200-remake/files/4499799/MPAGD_GAMES.zip)

:

kashban, 2020-06-01:
Thanks OSS, we will give it a try.

So far I am not aware of any support for those mods, since we only adapted the emulator, but did not develop it.

cwahlmann, 2020-06-06:
Hi! Do you know where to find any specification for these mods? If I get any, I will give it a try.

bushy555, 2020-07-12:
Hi,
The Modifications are available in the FILES section of the 'VZ200 / VZ300 fans' group on Facebook.
Failing that, they are NOW available on my little website.   https://vz200.org/bushy/
Both these "German Mod" and the "Australian Mod" are sitting under the title "HARDWARE" as downloadable PDF files.

Article _ German 256x192 graphics mod. "German Mod"
Article _ German 256x192 graphics mod in English. "German Mod"
Article _ Joe Leon's super high graphics mod. part #1. "Australian Mod"
Article _ Joe Leon's super high graphics mod. part #2. "Australian Mod"

--------------

A quick summary about these modifications; taken from Guy Thomason's VZEM Emulator readme file.

EXTENDED GRAPHICS

The “Super VZ Graphics” hardware modification is emulated. This provides
support for all the graphics modes the video chip is capable of (Motorola 6847)

To active the extended graphics modes, type the following from the emulator:

GM0	OUT 32,0	64x64		Color			1024 bytes
GM1	OUT 32,4	128x64		Monochrome		1024 bytes
GM2	OUT 32,8	128x64		Color			2048 bytes
GM3	OUT 32,12	128x96		Monochrome		1536 bytes
GM4	OUT 32,16	128x96		Color			3072 bytes
GM5	OUT 32,20	128x192		Monochrome		3072 bytes
GM6	OUT 32,24	128x192		Color			6144 bytes
GM7	OUT 32,28	256x192		Monochrome		6144 bytes

Then activate the mode using the MODE(1) command or POKE 26624,8.

The VZ200 memory map can only access 2k video ram. For graphics modes that
occupy more than 2k (eg GM7), bank switching is used.

The byte written to port 32 is decoded via the following bits

xxxmmmbb

Where xxx is not used, mmm is the graphics mode, and bb is the bank. So to
activate GM7 bank 0, the output byte would be 0011100 binary or 28 decimal.
To activate GM7 bank 1, the output byte would be 0011101 binary or 29 decimal.

For whatever bank is active, reads/writes to the 2k video memory at 7000h will
affect the screen. For GM7, pixel rows 0-63 are active for bank 0, 64-127 for
bank 1 and 128-191 for bank 2.

For further information on extended vz graphics, read the following articles
(available from VZAlive)

VZ Super Graphics by Joe Leon
Ultra Graphics Adapter by Matthew Sorrell.

Support has been added for the German Graphics Mod.
From the main menu, select options -> extended graphics -> german.
The German modification only supports GM7, the 256x192 monochrome mode. To
enable the mode, set bit 4 of address 30779, eg POKE 30779,8
Then activate the hi-res screen by either the MODE(1) command or POKE 26624,8.

The bank switching is controlled by port 222, eg

OUT 222,0	selects bank 0
OUT 222,1	selects bank 1
OUT 222,2	selects bank 2
OUT 222,3	selects bank 3

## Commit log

2019-09-17 Doku: Bilder Teaser und Social Preview mit neu gerenderten Bilder hinterlegt
2019-09-22 doku: screenshots und bilder
2020-02-18 Korrektur des Sources
2020-03-16 Doku: Absage Makerfaire und Video
2020-03-21 Screenshots des 3D-Modells hinzugefügt
2020-03-28 Kleinere Anpassungen und Korrekturen
2020-05-15 #15: Fusion 3d-modelle
    [Monitor_5-Zoll.f3d]
2020-05-21 #15 Readme's angepasst; neue Version des Emulators (mit ASM-Multtipart Source-Loader)
